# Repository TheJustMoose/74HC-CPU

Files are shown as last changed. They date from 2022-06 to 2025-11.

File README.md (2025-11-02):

# 74HCPU

Not a very scary instruction set discrete logic processor.

* 8 bit data
* 16 bit address / 64KB RAM
* 16 instructions
* 8 data registers and 4 pointer registers in 2 banks
* 1 flag register in IO port

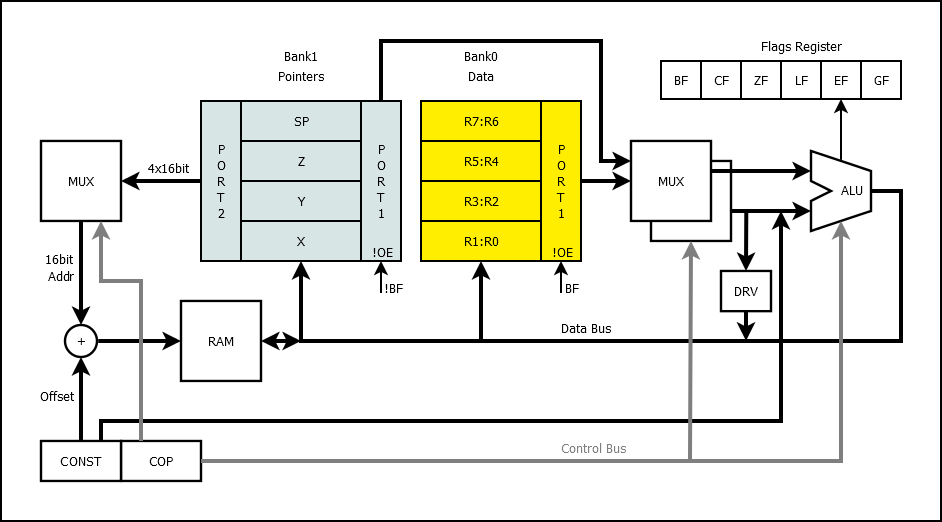
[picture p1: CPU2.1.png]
CPU structure


## How CPU works?

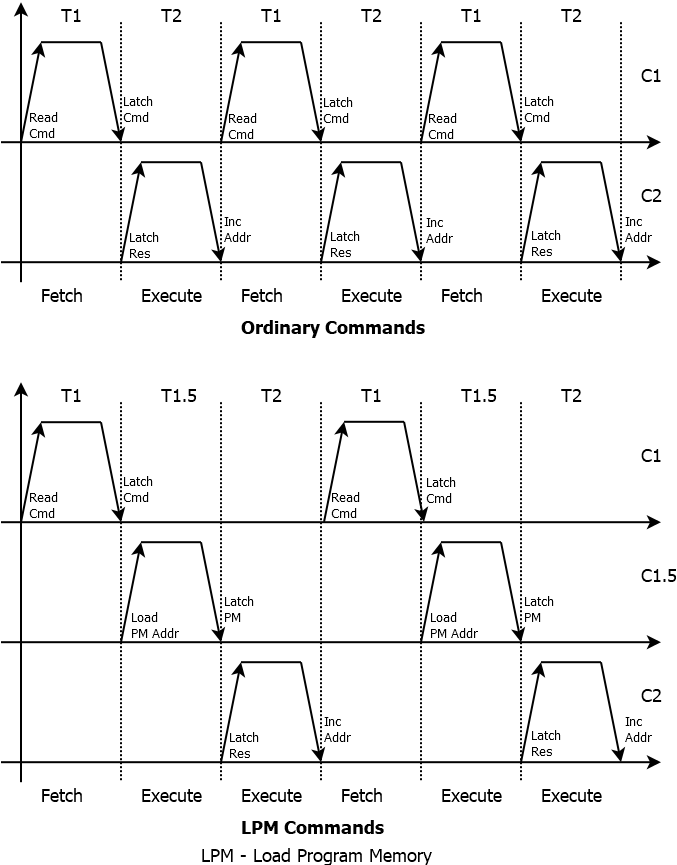
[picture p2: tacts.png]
CPU tacts


[Layers of PCBs](layers/README.md)

## Instruction list

```
|----------------------------------------------|f|
|   HIGH BYTE    |    LOW BYTE   |  HIGH BYTE  |a|
|0 1 2 3  4 5 6 7 8 9 A B C D E F|   (again)   |g|
|   4   +   3 + 1 + 3  +    5    = 16          |l|
|----------------------------------------------|s|
|   ADD |  DST |C| SRC |-|Z|z|I|i| 00 0000 0000|*|
|  ADDC |  DST |C| SRC |F|Z|z|I|i| 10 0001 0000|*|
|   AND |  DST |C| SRC |-|Z|z|I|i| 20 0010 0000|*|
|    OR |  DST |C| SRC |-|Z|z|I|i| 30 0011 0000|*|
|   XOR |  DST |C| SRC |-|Z|z|I|i| 40 0100 0000|*|
|   MUL |  DST |C| SRC |-|Z|z|I|i| 50 0101 0000|*|
|   UNO |  DST |0|-|TYP|F|-|-|-|-| 60 0110 0000|*|
|   MOV |  DST |0| SRC |*|Z|z|I|i| 70 0111 0000| |
|   LPM |  DST |W|EXT|D|U|OFFSET4| 80 1000 0000| |
|    LD |  DST |0|EXT|D|U|OFFSET4| 90 1001 0000| |
|    IN |  DST |  PORT   |Z|z|I|i| A0 1010 0000| |
|--------------|7-8-9-A-B|-------|-------------|-|
|   OUT |  SRC |  PORT   |O|o|X|x| B0 1011 0000| |
|    ST |  SRC |0|EXT|D|U|OFFSET4| C0 1100 0000| |
|   CMP |  DST |C| SRC |-|   -   | D0 1101 0000|+|
|  CMPC |  DST |C| SRC |-|   -   | E0 1110 0000|+|
| BRNCH |  CALL  | 8 bit OFFSET  | F0 1111 0000| |
| BRNCH |   JMP  | 8 bit OFFSET  | F1 1111 0001| |
| BRNCH |   RET  | 8 bit +STACK  | F2 1111 0010| |
| BRNCH |  RETI  | 8 bit OFFSET  | F3 1111 0011| |
| BRNCH |    JL  | 8 bit OFFSET  | F4 1111 0100| |
| BRNCH |    JE  | 8 bit OFFSET  | F5 1111 0101| |
| BRNCH |   JNE  | 8 bit OFFSET  | F6 1111 0110| |
| BRNCH |    JG  | 8 bit OFFSET  | F7 1111 0111| |
| BRNCH |    JZ  | 8 bit OFFSET  | F8 1111 1000| |
| BRNCH |   JNZ  | 8 bit OFFSET  | F9 1111 1001| |
| BRNCH |    JC  | 8 bit OFFSET  | FA 1111 1010| |
| BRNCH |   JNC  | 8 bit OFFSET  | FB 1111 1011| |
| BRNCH |   JHC  | 8 bit OFFSET  | FC 1111 1100| |
| BRNCH |  JNHC  | 8 bit OFFSET  | FD 1111 1101| |
| BRNCH | AFCALL | Hi 8 bit ADDR | FE 1111 1110| |
| BRNCH |NOP/STOP|   1111 111x   | FF 1111 1111| |
|----------------------------------------------|-|
```

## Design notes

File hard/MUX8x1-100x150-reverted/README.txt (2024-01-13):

This multiplexer is similar to MUX8x1-100x150, but the output connector is reversed.

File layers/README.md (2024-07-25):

# 74HCPU PCB layers

## Layer 1 (top)

<table>
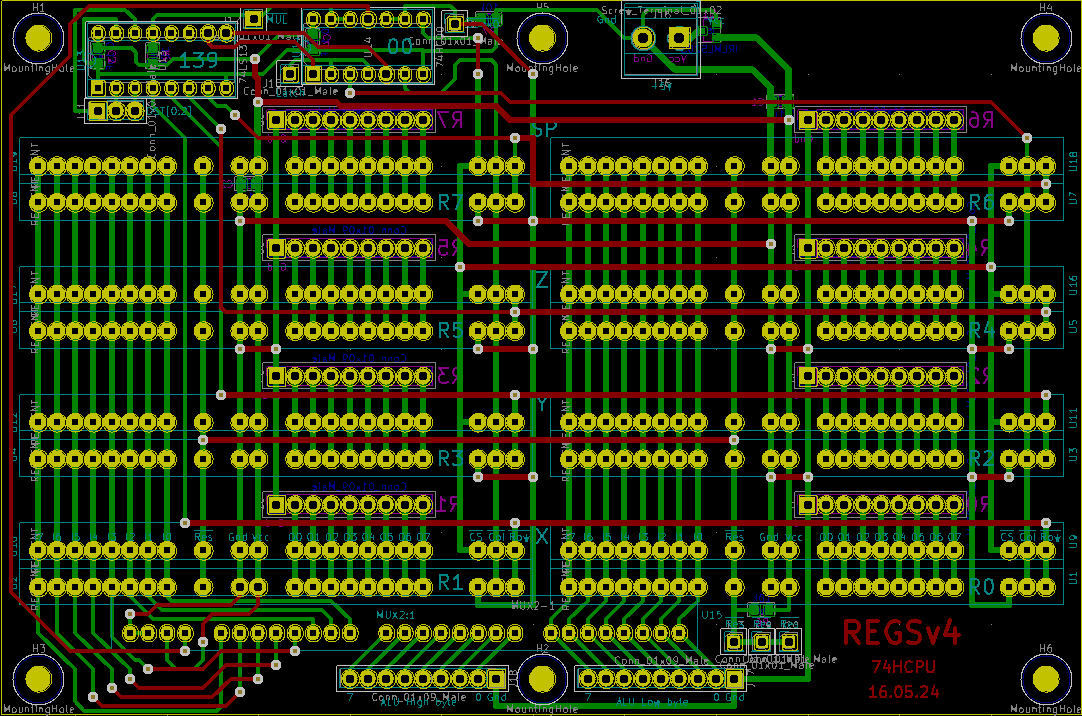
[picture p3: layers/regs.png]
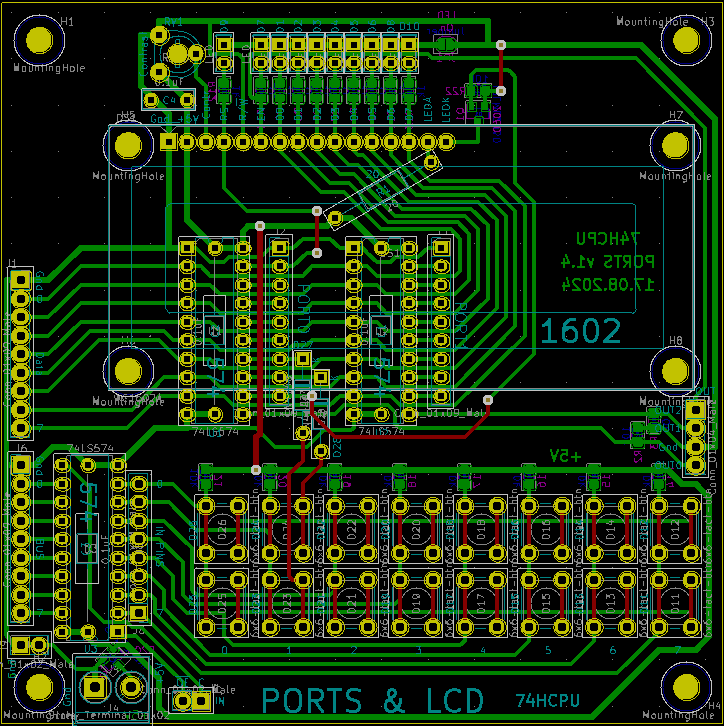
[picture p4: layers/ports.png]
<tr><td></td><td></td></tr>
</table>

## Layer 2

<table>
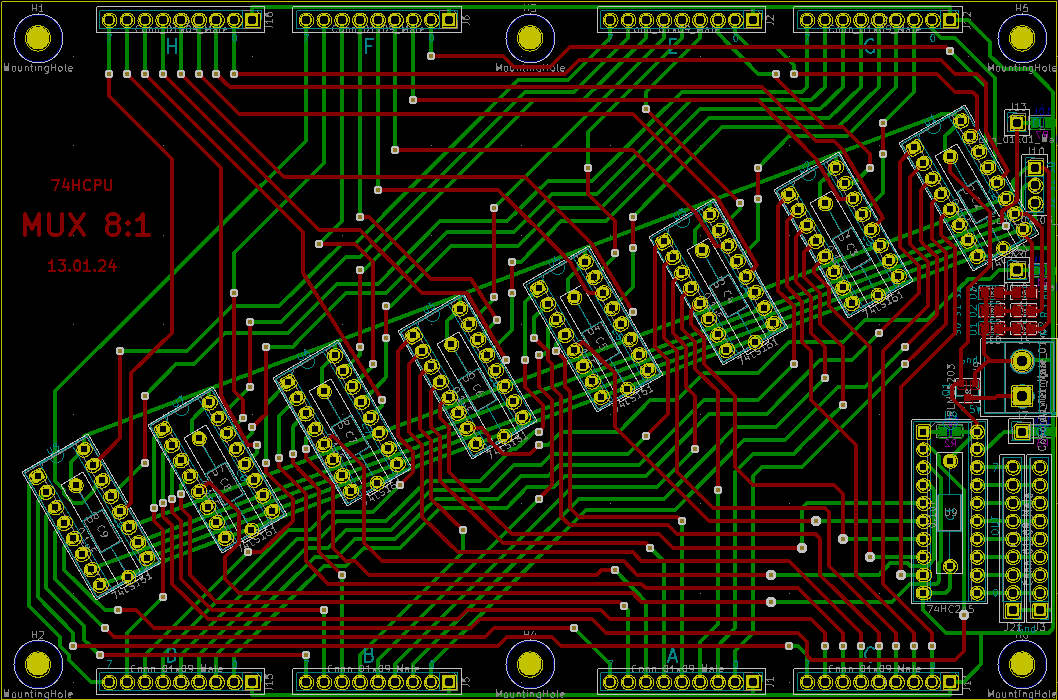
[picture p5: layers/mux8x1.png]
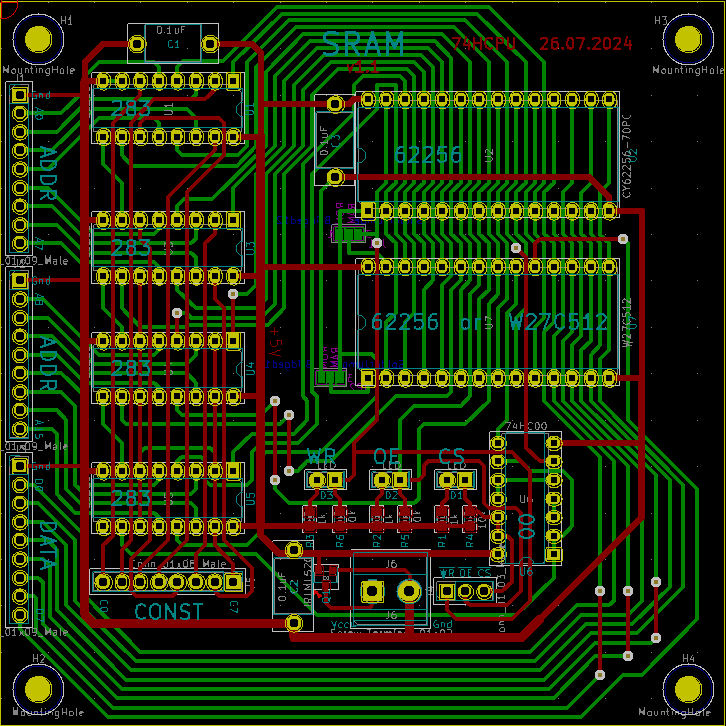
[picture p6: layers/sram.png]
<tr><td></td><td></td></tr>
</table>

## Layer 3

<table>
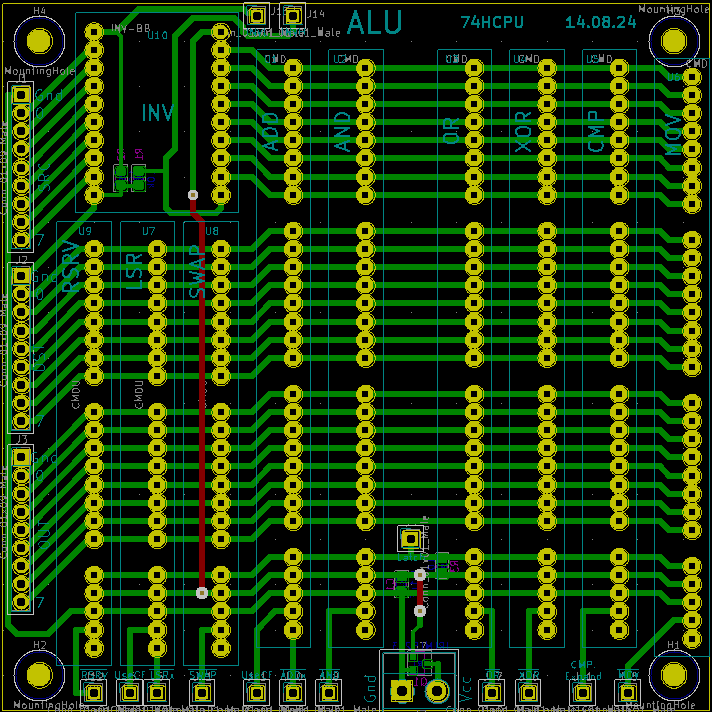
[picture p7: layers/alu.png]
<tr><td></td><td></td></tr>
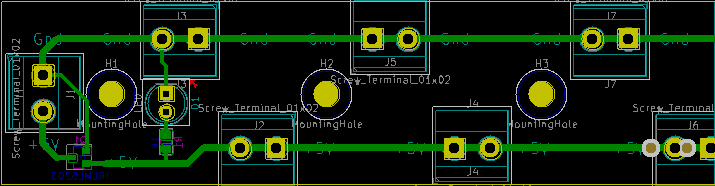
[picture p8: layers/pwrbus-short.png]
<tr><td></td><td></td></tr>
</table>
<table>
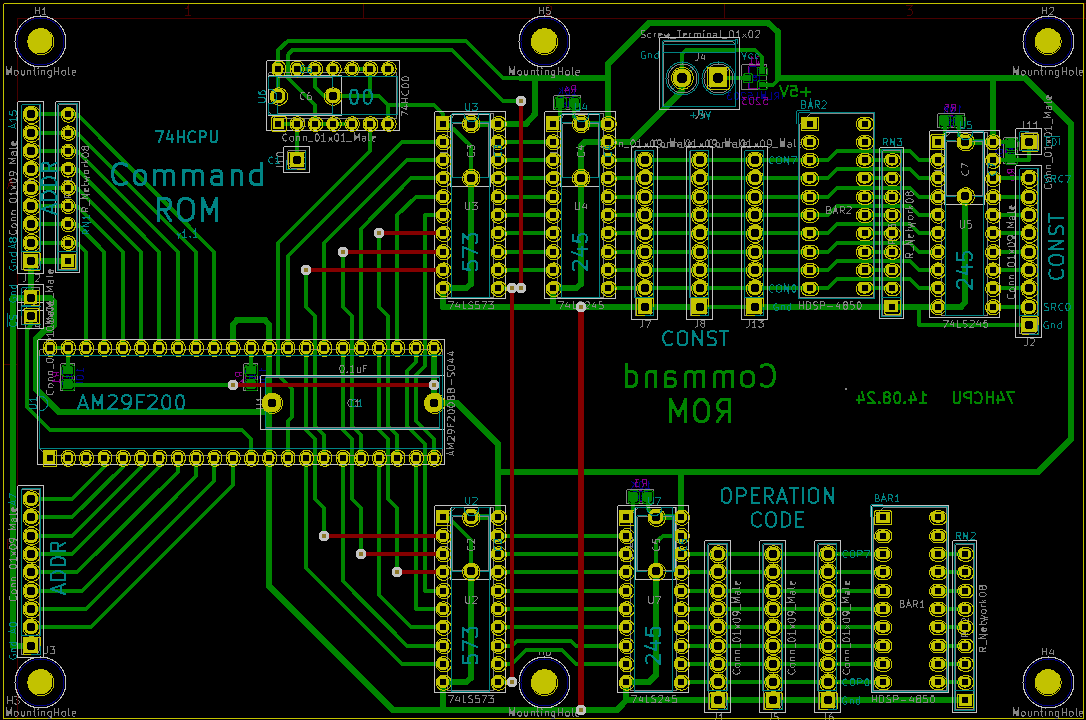
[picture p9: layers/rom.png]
<tr><td></td><td></td></tr>
</table>

## Layer 4 (bottom)

<table>
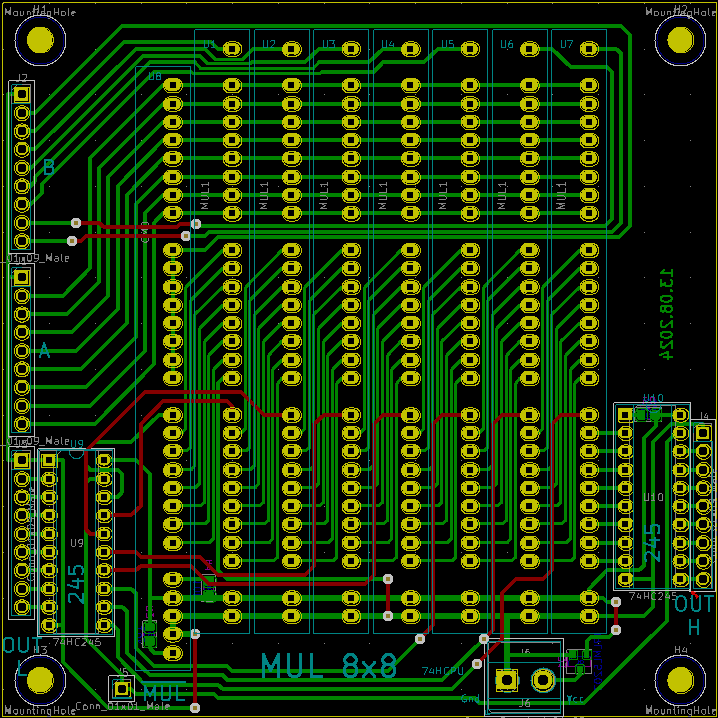
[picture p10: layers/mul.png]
<tr><td></td><td></td></tr>
<tr><td></td><td></td></tr>
</table>
<table>
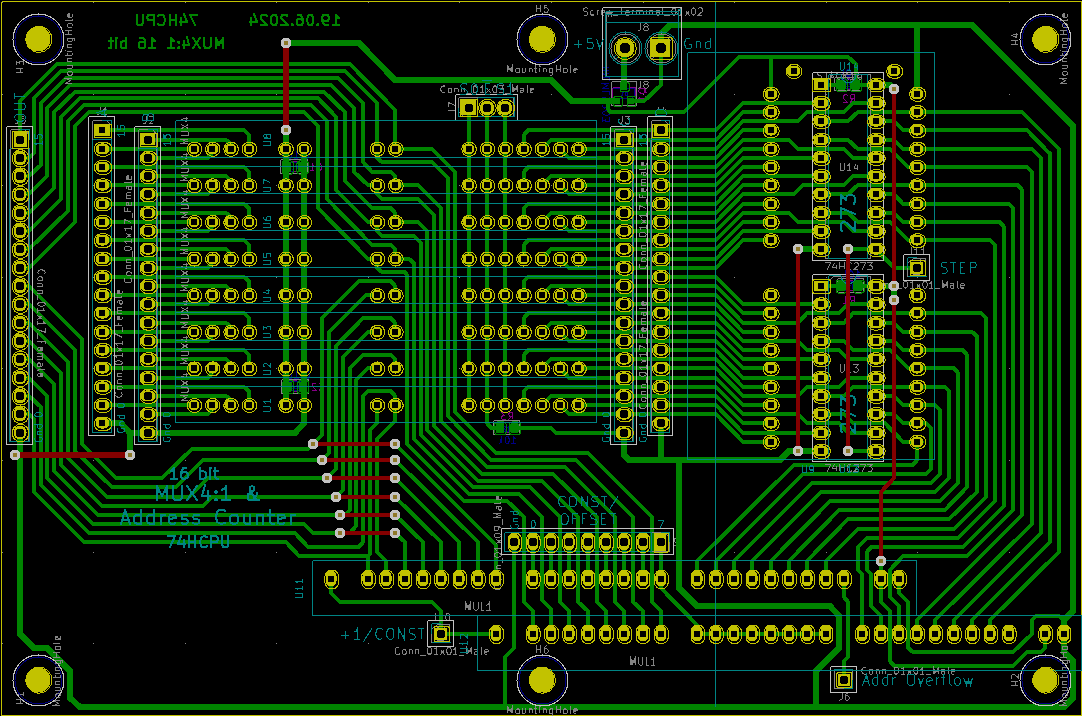
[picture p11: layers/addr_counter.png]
<tr><td></td><td></td></tr>
</table>

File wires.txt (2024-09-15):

Список пинов/проводов/контактов на разных платах и их значение:

ROM
A0-A15 - вход, шина адреса, какие данные читать из ROM
CS - вход, включить микросхему ROM
C1 - вход, сигнал, по которому данные читаются из ROM и записываются в регистры
COP0-COP7 - шина, содержит команду, которую нужно выполнить
 (при выполнении команды LPM содержит старший байт данных)
CNST0-CNST7 - шина, содержит константу или адрес, которые используются в команде
BUS0-BUS7 - шина, содержит константу, которую можно подать шину данных,
 активируется сигналом LDI
LDI - вход, сигнал, переводит шинный формирователь в активное состояние и на шине данных появляется константа

RAM
A0-A15 - шина адреса
D0-D7 - шина данных, активируется сигналом логического 0 на входе OE
C0-C7 (CONST) - смещение, складывается со значением на шине адреса,
 сумма подаётся на шину адреса ОЗУ
CS - логический 0 активирует ОЗУ
OE - логический 0 подключает выходы озу к шине данных
WR - логический 0 производит запись данных с шины данных
 в ячейку памяти, адрес которой равен сумме шины адреса и константы

Regs
ALU Low Byte - вход данных, подключен к АЛУ, младший байт
ALU High Byte - вход данных, подключен к АЛУ, старший байт, нужен для команды MUL
 (эти же входы могут получать данные с RAM, ROM (LPM), портов)
Bank0 - вход, активирует регистры из банка 0
 (если подать логическую единицу включится банк 1)
Latch - вход, по этому сигналу данные запишутся в регистр
DST[0:2] - вход, в какой регистр писать данные по сигналу Latch
MUL - вход, активируется логическим 0, если активен - данные с ALU Low/High Byte
 будут записаны в два соседних регистра
Res - вход, если подать логическую 0, то все регистры обнулятся
R0-R7 - выходы регистров, подключаются к мультиплексорам

ALU
SRC - вход данных 1, подключен через мультиплексоры к регистрам данных
DST - вход данных 2, подключен через мультиплексоры к регистрам данных
OUT - выход данных, результаты вычисления
INVL, INVH - вход, инвертировать данные, полученные со входа SRC
 (можно отдельно младшую и старшую половны)
Latch - вход, по этому сигналу защёлкиваются данные внутри команд
 (сейчас не используется, данные сразу оказываются на выходе)
входы активации команды, записанные ниже, можно активировать только по одной штуке
 (иначе случиться короткое замыкание и всё сгорит):
ADDx - вход, активировать команду сложения
UseCF - нужно ли дополнительно прибавлять бит CF к сумме (ADDC)
AND/OR/XOR - логические команды
MOV - просто передаёт данные со входа SRC на выход OUT
команда CMP всегда сравнивает SRC и DST и всегда выдаёт результат на своих выходах
 (у этой команды OUT является входом, на нём проверяется наличие нуля)
CMP.Expand превращает команду CMP в CMPC, то есть, в сравнении участвует флаг CF

унарные команды, получают данные на входе DST, выдают результат на выходе OUT:
SWAP - активирует команду SWAP, переставить местами нибблы
LSRx - побитовый сдвиг вправо
UseCF - в процессе сдвига участвует флаг CF
RSRV - активирует команду RSRV, собственно, туда можно воткнуть что угодно ;)

MUL
A - вход данных 1, подключен через мультиплексоры к регистрам данных
B - вход данных 2, подключен через мультиплексоры к регистрам данных
OUTL - выход данных, результат вычисления, младший байт
OUTH - выход данных, результат вычисления, старший байт
MUL - вход, при подаче логического 0 выходы данных переходят из Z состояния в рабочее

MUX8:1
A-H - 8 входов данных, подключаются к регистрам
OUT - выход данных, подключается к ALU, MUL, ...
OE - вход, при подаче логического 0 выход данных переходит из Z состояния в рабочее
S0-S7 - входы, выбирают какой из входов данных будет подключен к выходу
EL, EH - входы, позволяют занулить один или оба ниббла выходных данных

Ports
Data - вход данных, подключен к LCD и паре регистров
BUS - выход данных, активируется логическим 0 на входе IN0.OE
IN0.C - вход, защёлкивает данные в выходном регистре по фронту импульса
IN0.OE - вход, подключает выходной регистр к шине BUS по логическому 0 на этом входе
OUT0 - защёлкивает данные в PORT0 по фронту импульса
OUT1 - защёлкивает данные в PORT1 по фронту импульса
OUT2 - подключен ко входу E LCD 1602, подробности в описании LCD 1602
регистр PORT0 имеет выходы, подключенные к входу RS LCD, кнопкам, подсветке LCD

Addr Counter
A, B, C, D - 16 бит входы мультиплексора,
 вход C подключен к выходу стека, вход D подключен к регистру адреса
O(OUT) - выход мультиплексора
+1/CONST - вход, при логической 1 делает шаг вперёд на CONST,
 при логической 0 делает шаг вперёд на 1
STEP - вход, шаг происходит по фронту импульса
S0-S1 - входы, выбирают один из входов A, B, C, D и подключают его к O
E - вход, при подаче логического 0 зануляет выходы O
входы стека подключаются навесным монтажём к логике

Flags гипотетический
GT, LT, EQ, ZF, CF1, CF2 - входы флагов
C2 - тактовый вход
CF Enable - вход, разрешает запись флага CF
ZF Enable - вход, разрешает запись флага ZF
CMP Enable - вход, разрешает запись флагов GT, LT, EQ
Res - вход, если подать логическую 0, то все флаги обнулятся
 (кроме EQ, он инверсный)
GT, LT, EQ, ZF, CF(три раза) - вЫходы флагов
(плюс инверсные CF и ZF)
НЕ ХВАТАЕТ!
HCF, BG, DBG

CMD_DEC гипотетический
входы:
COP0-COP3
C1
C2
SRC0-SRC2
выходы:
ADD, ADDC, ....
RAM_OE
RAM_WR
RAM_CS
CMP_EN
CF_EN
ZF_EN
LSR, SWAP, RSRV
UseCF
WILL_WR2REG
LATCH_REG
НЕ ХВАТАЕТ!
INVL, INVH
?

JUMPS гипотетический

Toggle

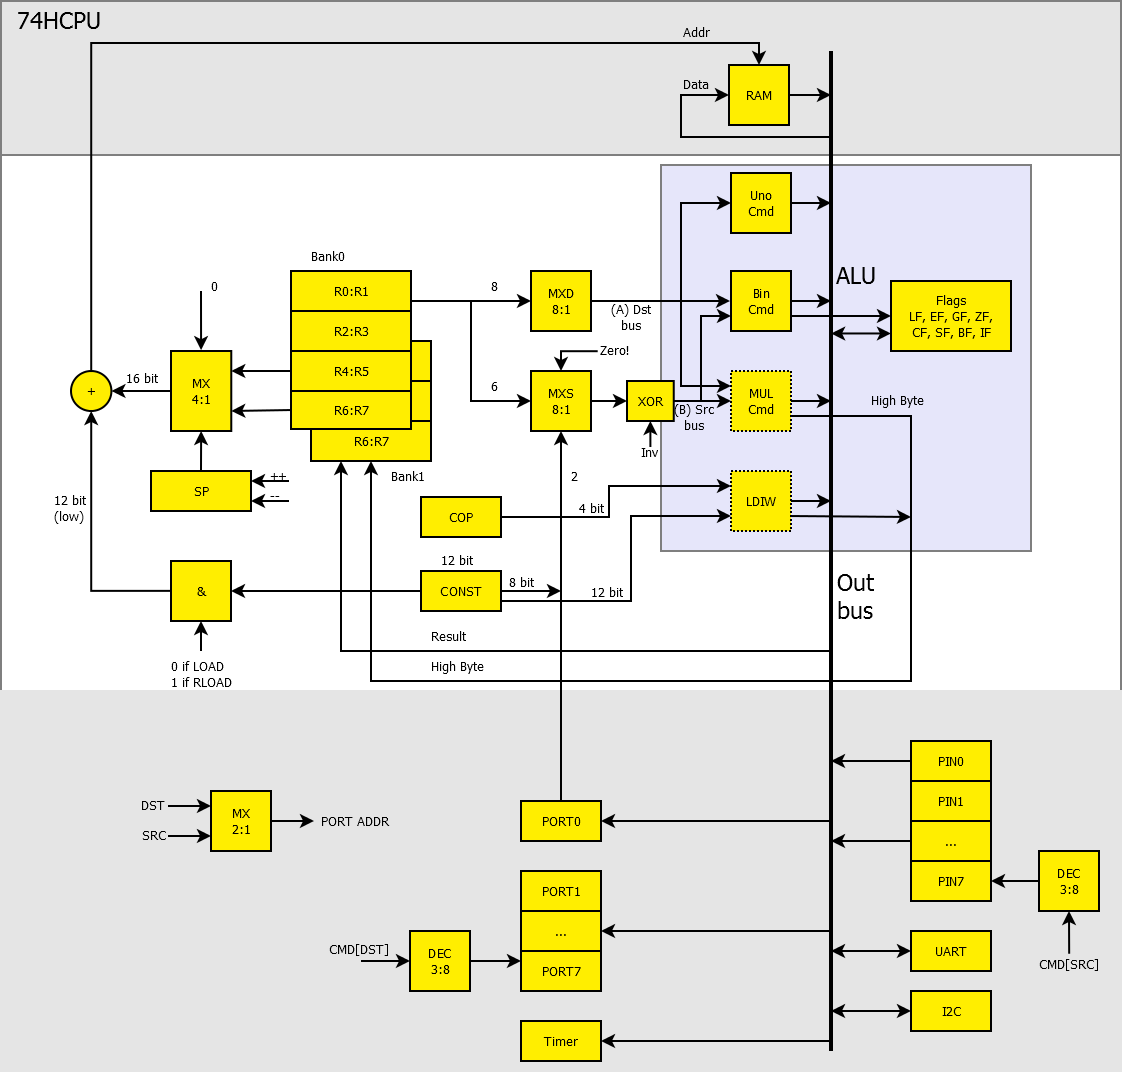
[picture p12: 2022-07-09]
CPU.png

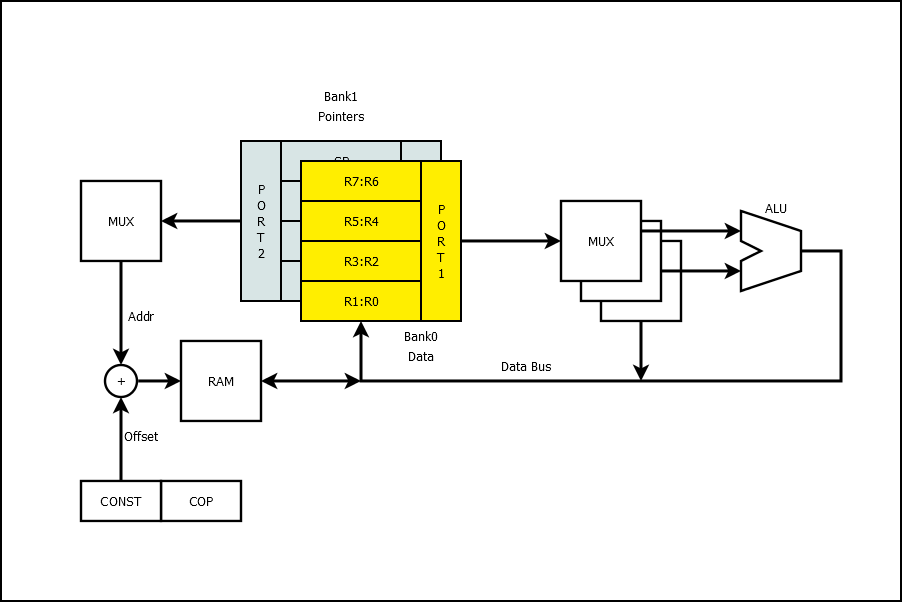
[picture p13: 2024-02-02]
CPU2.png

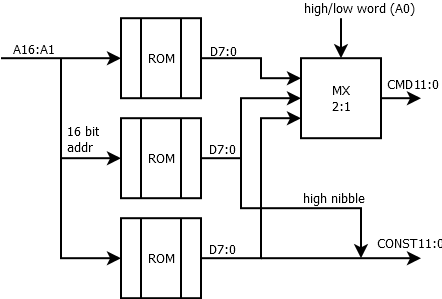
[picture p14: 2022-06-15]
Trash/ROM.png

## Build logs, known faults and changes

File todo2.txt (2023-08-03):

сделать стек для вызовов функций
(платы есть, нужно только спаять, и воткнуть в монтажку)
реализовать команду INC
спаять 3x MUX8:1
спаять 8x Reg
выкинуть из АЛУ команду INV
вынуть из АЛУ RAM
поместить плату RAM под АЛУ
поменять местами СЗР и МЗР у мультиплексоров, чтобы кабели не перекручивались
добавить защиту от переполюсовки, везде!!
переделать CMD_DEC, поменять местами BRNCH и CMP, добавить генерацию сигнала переключения на константу
добавить светодиодов на генератор тактовых сигналов
+придумать/переделать сигнал LATCH для OUT/LCD
новая плата портов
написать простейшие функции вывода на LCD
написать простейший калькулятор :)
+нарисовать схему тактового генератора
добавить в неё третий такт для LPM
нарисовать плату тактового генератора
новая плата RAM
собрать плату регистров, например из stripboard-а
перекоммутировать проводочки src/dst
протестировать (написать тесты на все команды)
сделать плату UART
дождаться новых регистров
+дождаться счётчиков из Чип-Дипа
спаять новые регистры
реализовать автоинкремент указателей!
переделать счётчик адреса на MUL1
сделать его 16 битным
дождаться мультиплексора 16 бит
добавить к счётчику адреса мультиплексор 16 бит
реализовать команду LPM, без неё совсем грустно
написать ассемблер, опять
проверить максимальную тактовую частоту!!
добавить к регистру флагов
 ещё один бит для переноса из 4 бита,
 ещё пинов, и, кажется, элемент ИЛИ для ForceCF == INC
добавить к условным переходам новый флаг
попробовать сделать команду compare, skip if not equal (или какое-то другое условие)
сделать плату для XOUT (две?)
реализовать команду XOUT
добавить для команды IN возможность инверсии
написать эмулятор 8051 ;)
поменять 1602 на какой-нибудь gLCD
реализовать механизм прерываний
найти старый RTC с параллельной шиной и вкрутить его
придумать что-то с таймерами
досыпать светодиодов на плату RAM
написать библиотеку функций
написать свой BASIC *ROFL*
опять таки, интерпретатор можно положить в ROM, а программу в RAM
добавить мультиплексор для команд ADDI/ANDI/...
написать какую-нибудь игру!
придумать, как прикрутить клавиатуру крупнее чем 16 клавиш ;)
придумать какую-то шину ввода-вывода для расширения железа!
 (а-ля ISA)

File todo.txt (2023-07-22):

ZF должен защёлкиваться по арифметическим командам, а не по CMPx
потерялись светодиоды индикации банков

проверить размер микросхем на плате регистра
проверить размер фрезы во фьюжене на плате регистра, поменять на 0.9
протравить пару регистров
набить пару регистров
набить и протестировать плату регистров
купить текстолита и лужёного провода
собрать новый фрезерный станок
купить новый монитор помельче
попробовать фрезернуть мелкую плату прям по контуру дорожек
 (только нету фрезы 0.5)
кажется, у АЛУ нет подключения шинного формирователя к BUS для команды OUT
добавить на плату АЛУ типа монтажку, ибо наверняка какой-нибудь микросхемы не хватит
добавить подписей пинов на плату АЛУ
собрать уже наконец пульт управления для проца

нарисовать свежих монтажек, с Т образным расположением площадок
(два размера, для мелких плат с флагами и для ROM)
написать ассемблер
написать отладчик
начать рисовать в KiCAD схемы модулей

+Proto50x70-4er
+Proto100x150
+Proto100x150-4er

07.11.2022:
+набить платы AND/OR/XOR
+набить платы MUX4:1
+пересобрать проц и протестировать
 (в результате должно стать больше места и меньше багов)
+нарисовать/заказать платы AND&ADD
 (а также новые MUX4:1 и RegLED, регистр флагов?)
+протравить/набить платы RegLED
переделать монтажку регистров на 4 платы
набить плату RegLED
+сделать плату LCD, поставить на освободившееся место!
+протравить/набить плату CMP
что-то сделать с оставшимися платами INV, MOV
+начать собирать регистр флагов на освободившемся месте
+переделать команды условных переходов О_О
добавить команды SWAP, SHL, SHR
+что-то придумать с хранением бита переноса
сделать стек поглубже
придумать уже подходящий код для тестирования!
+получить платы AND&ADD и сделать уже умножение! :))
поменять LCD 1602 на gLCD
протестировать максимальную частоту *ROFL*

перенести на плату ROM?
+перейти на 12бит коды операций? уже, фактически, 16 битные
+сделать MUX8:1?
добавить команд вычитания и т.п.?

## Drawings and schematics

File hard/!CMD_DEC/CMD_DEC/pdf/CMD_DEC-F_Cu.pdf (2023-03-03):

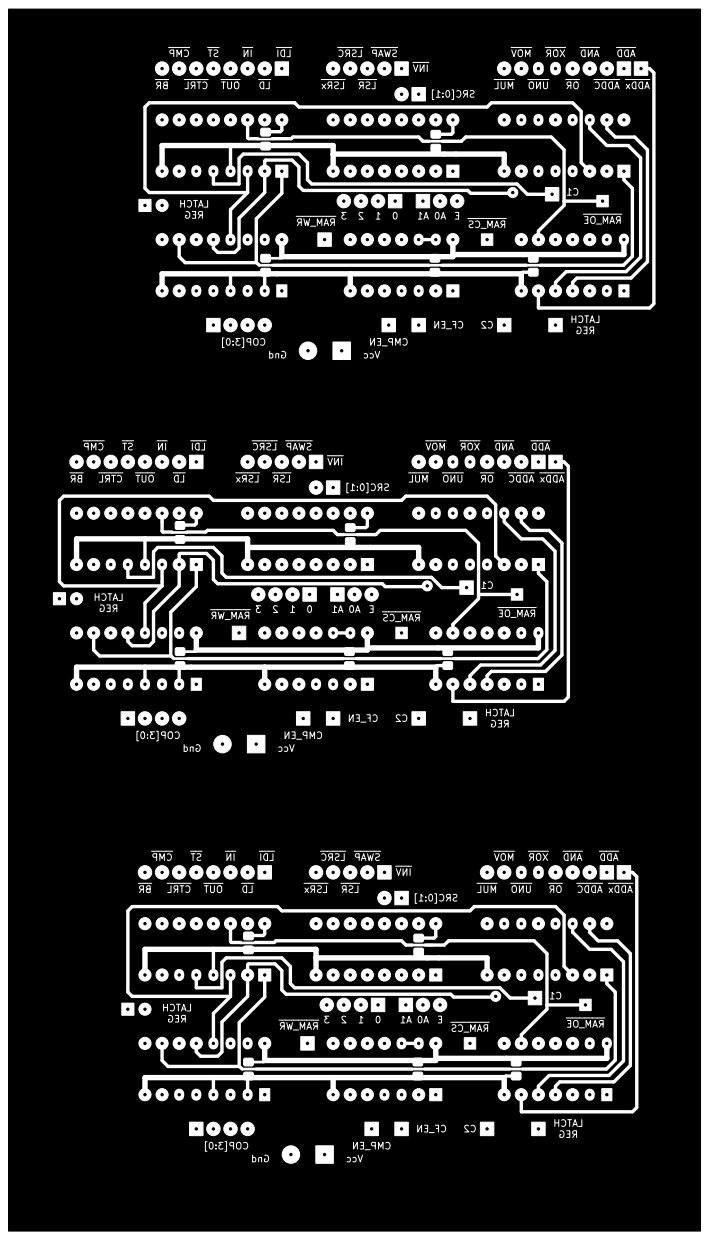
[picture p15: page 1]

CMP ST IN LDI

LSRx SRC[0:1] MUL UNO OR ADDC ADDx MOV XOR AND ADD

RAM_WR RAM_CS BR CTRL OUT LD

ADDC ADDx AND Gnd

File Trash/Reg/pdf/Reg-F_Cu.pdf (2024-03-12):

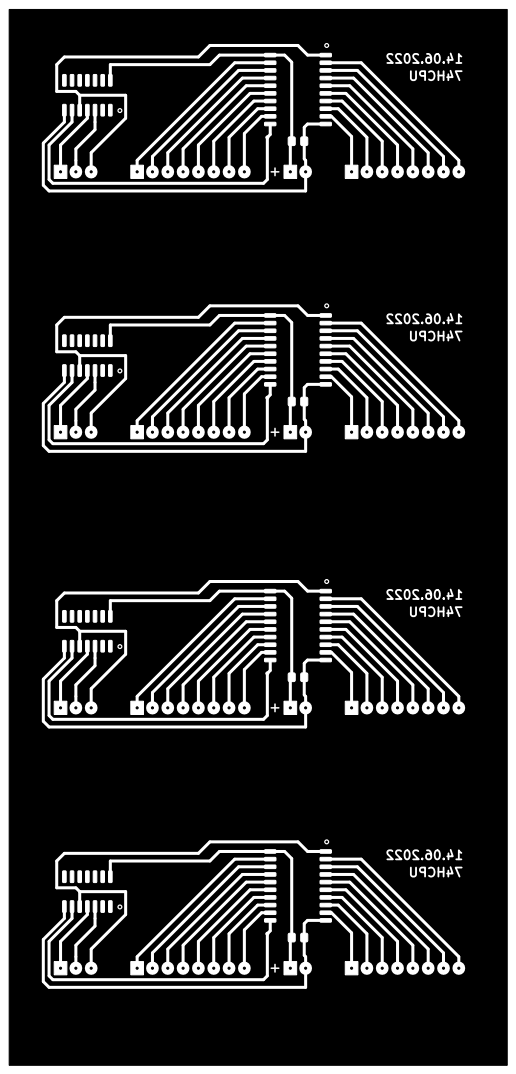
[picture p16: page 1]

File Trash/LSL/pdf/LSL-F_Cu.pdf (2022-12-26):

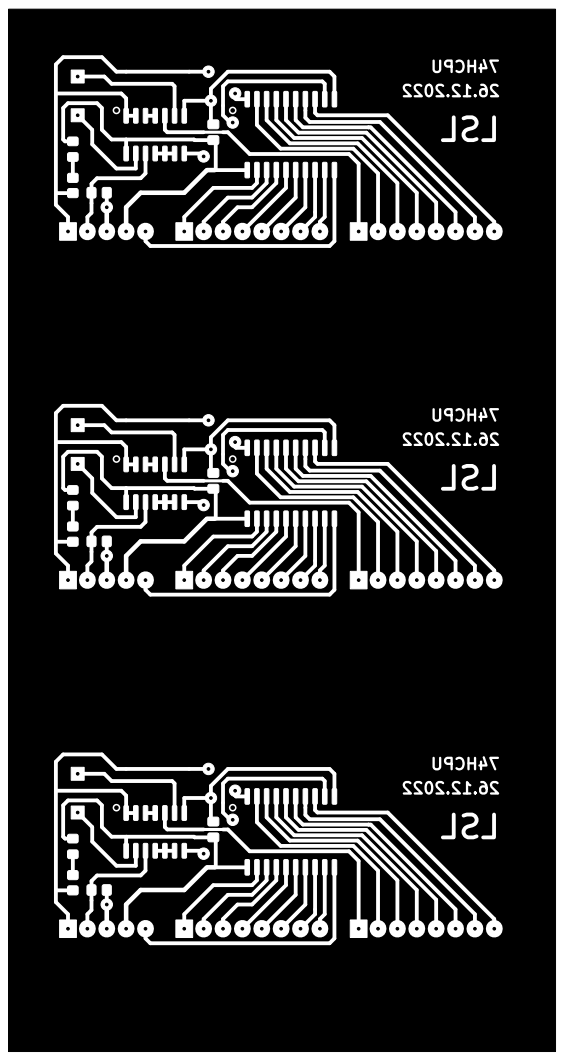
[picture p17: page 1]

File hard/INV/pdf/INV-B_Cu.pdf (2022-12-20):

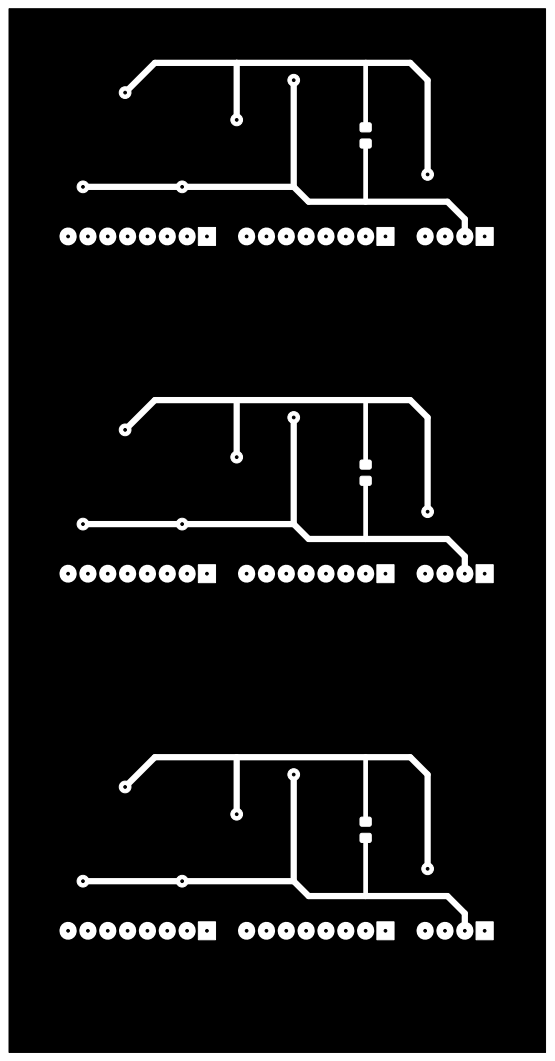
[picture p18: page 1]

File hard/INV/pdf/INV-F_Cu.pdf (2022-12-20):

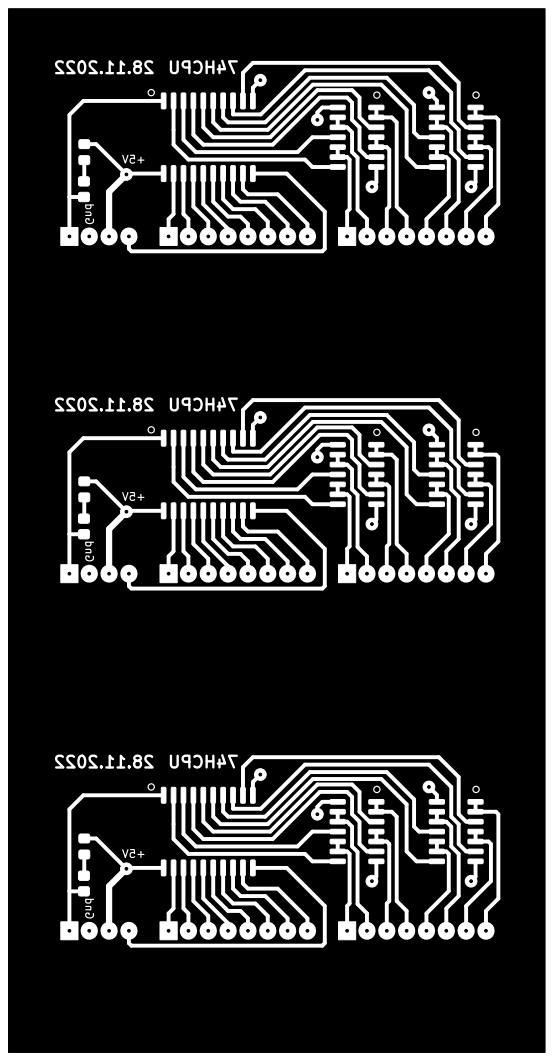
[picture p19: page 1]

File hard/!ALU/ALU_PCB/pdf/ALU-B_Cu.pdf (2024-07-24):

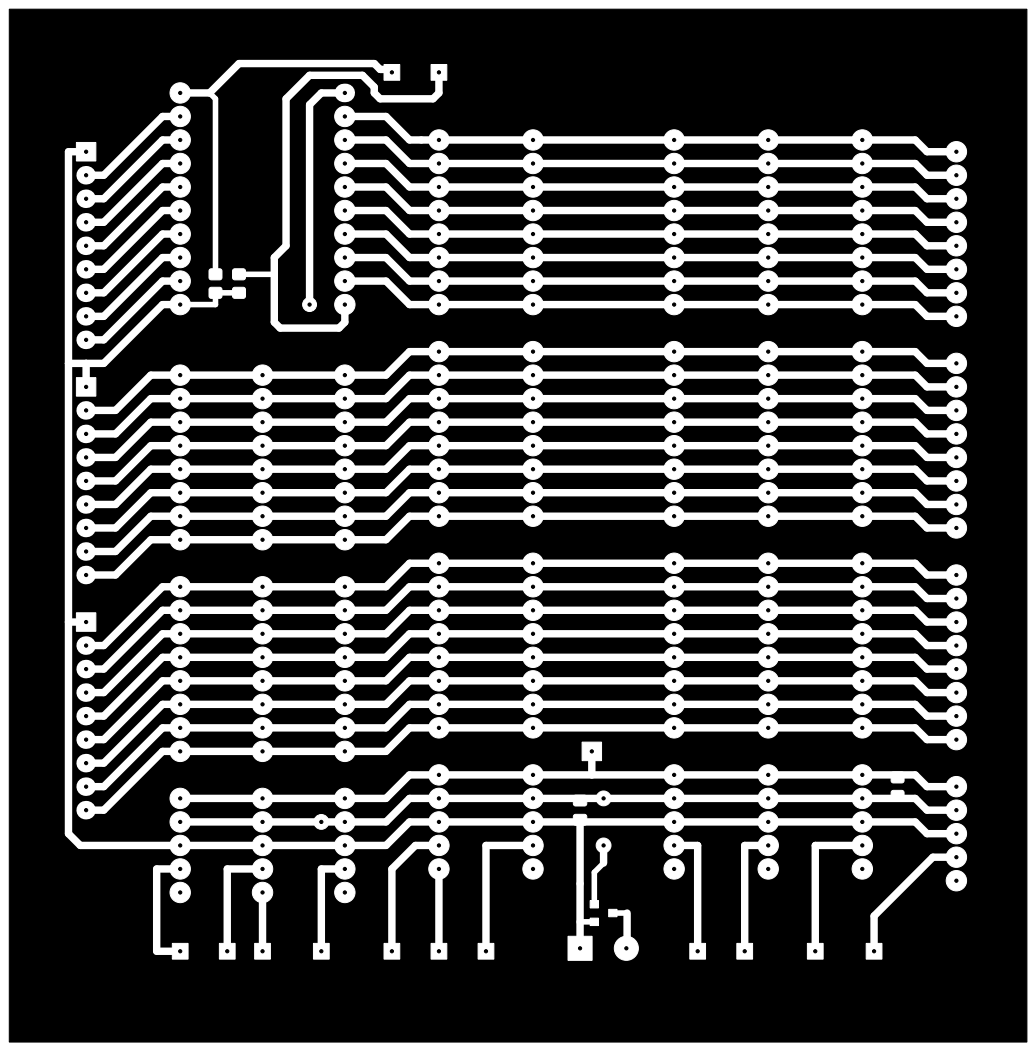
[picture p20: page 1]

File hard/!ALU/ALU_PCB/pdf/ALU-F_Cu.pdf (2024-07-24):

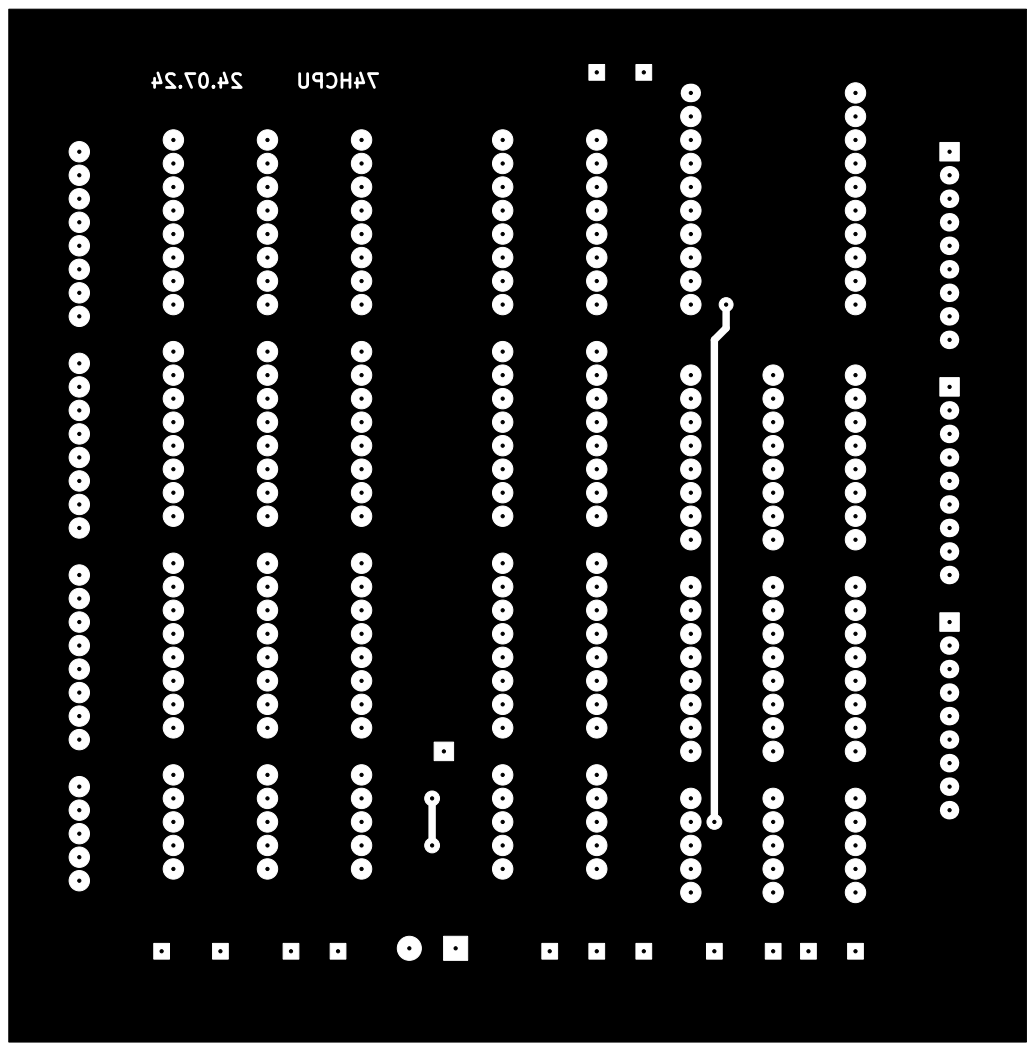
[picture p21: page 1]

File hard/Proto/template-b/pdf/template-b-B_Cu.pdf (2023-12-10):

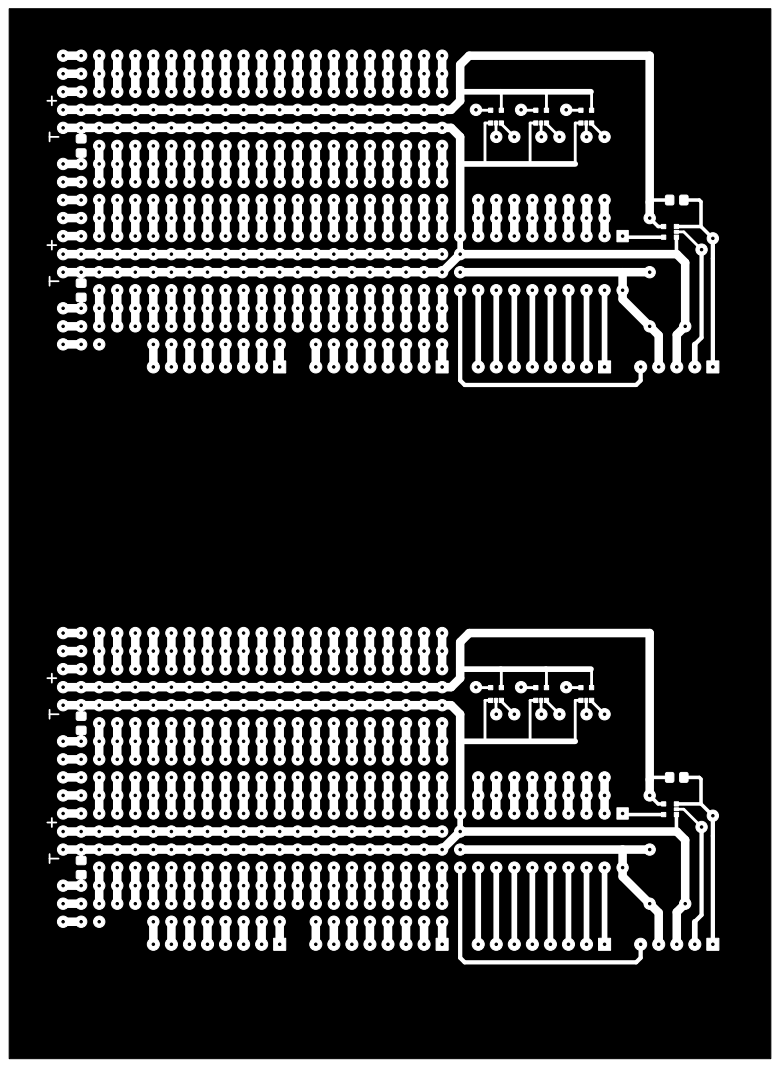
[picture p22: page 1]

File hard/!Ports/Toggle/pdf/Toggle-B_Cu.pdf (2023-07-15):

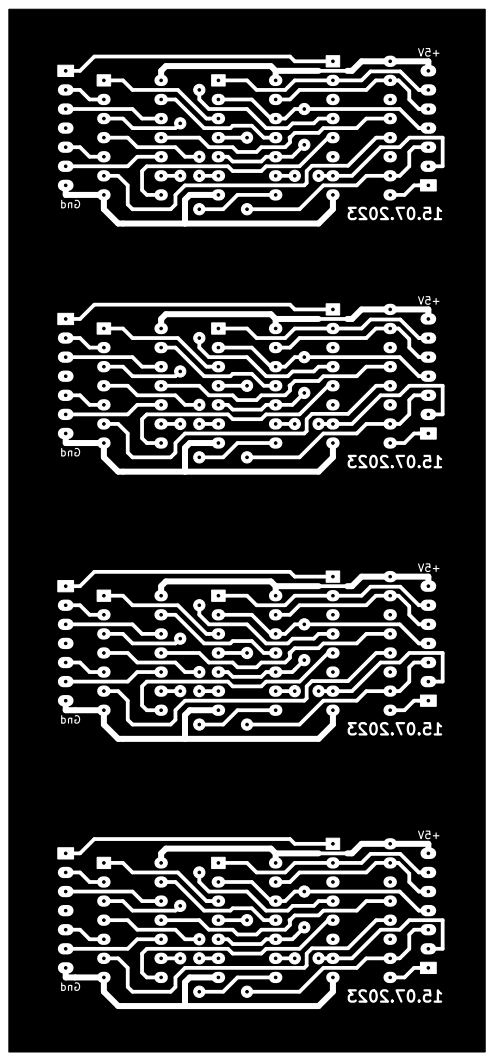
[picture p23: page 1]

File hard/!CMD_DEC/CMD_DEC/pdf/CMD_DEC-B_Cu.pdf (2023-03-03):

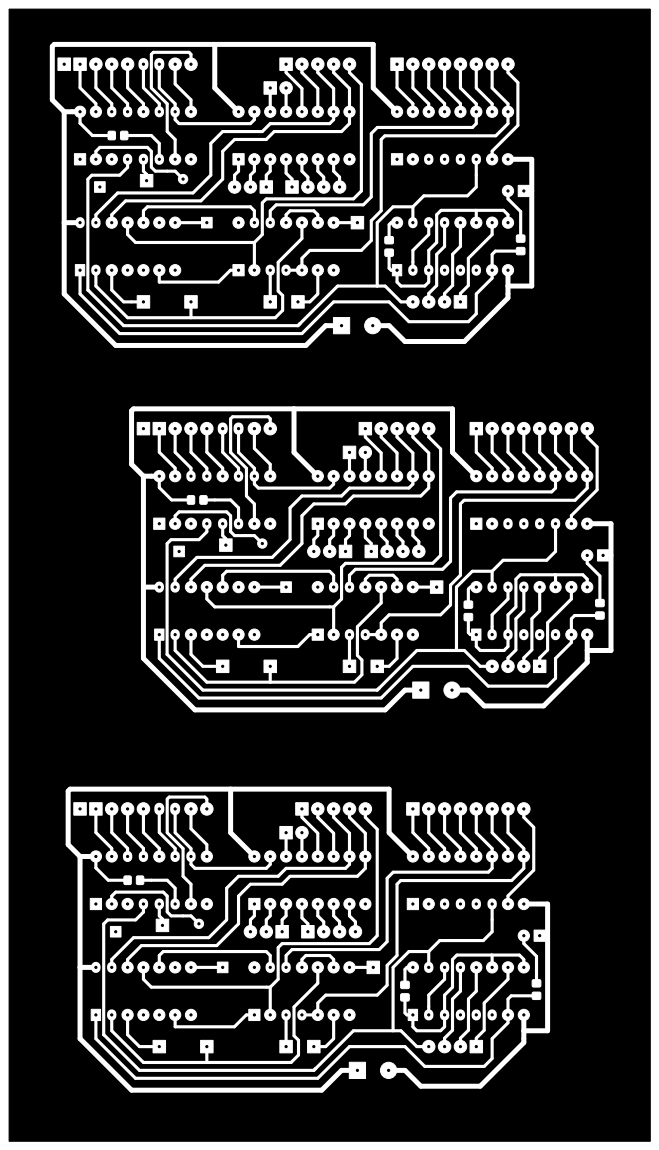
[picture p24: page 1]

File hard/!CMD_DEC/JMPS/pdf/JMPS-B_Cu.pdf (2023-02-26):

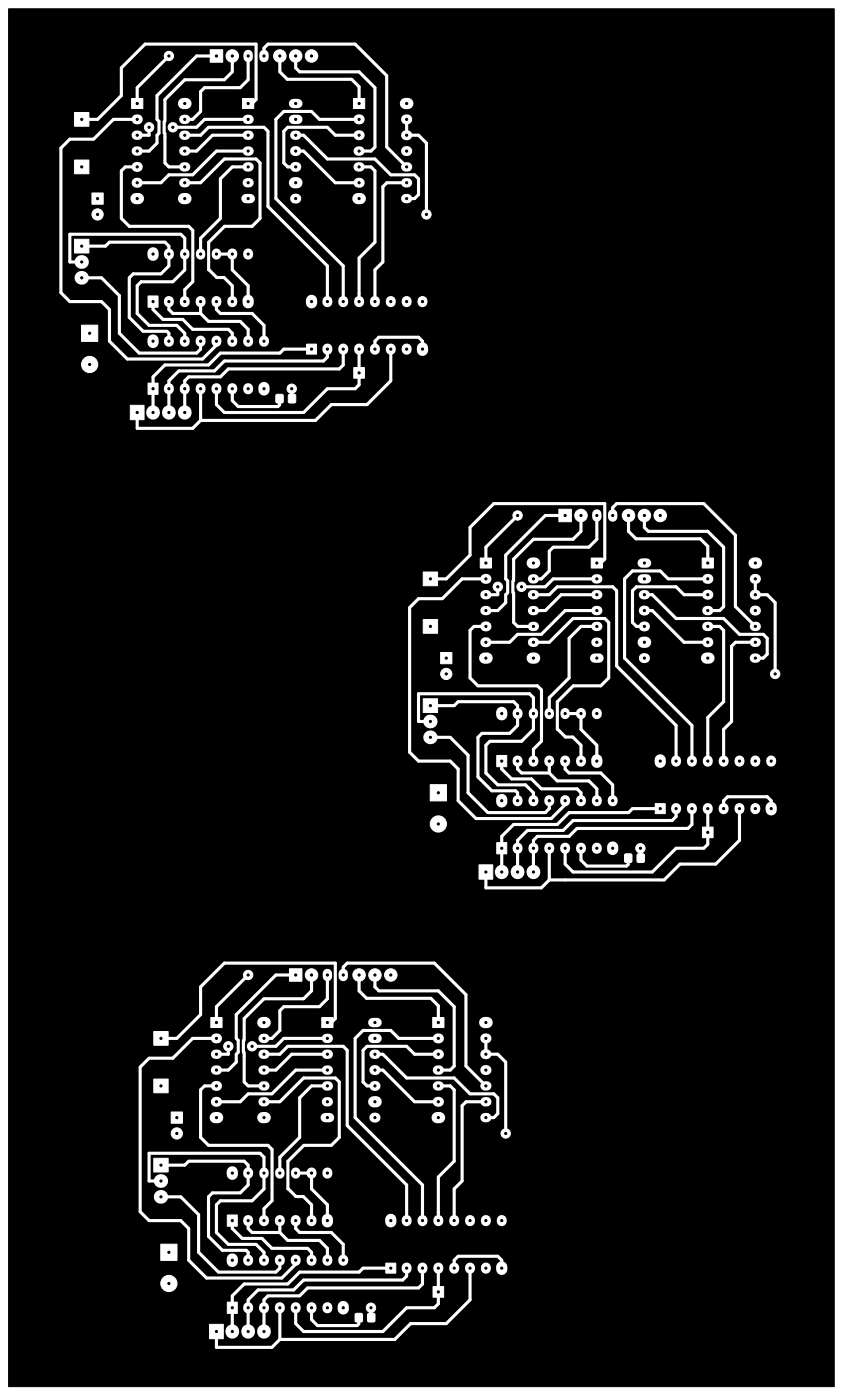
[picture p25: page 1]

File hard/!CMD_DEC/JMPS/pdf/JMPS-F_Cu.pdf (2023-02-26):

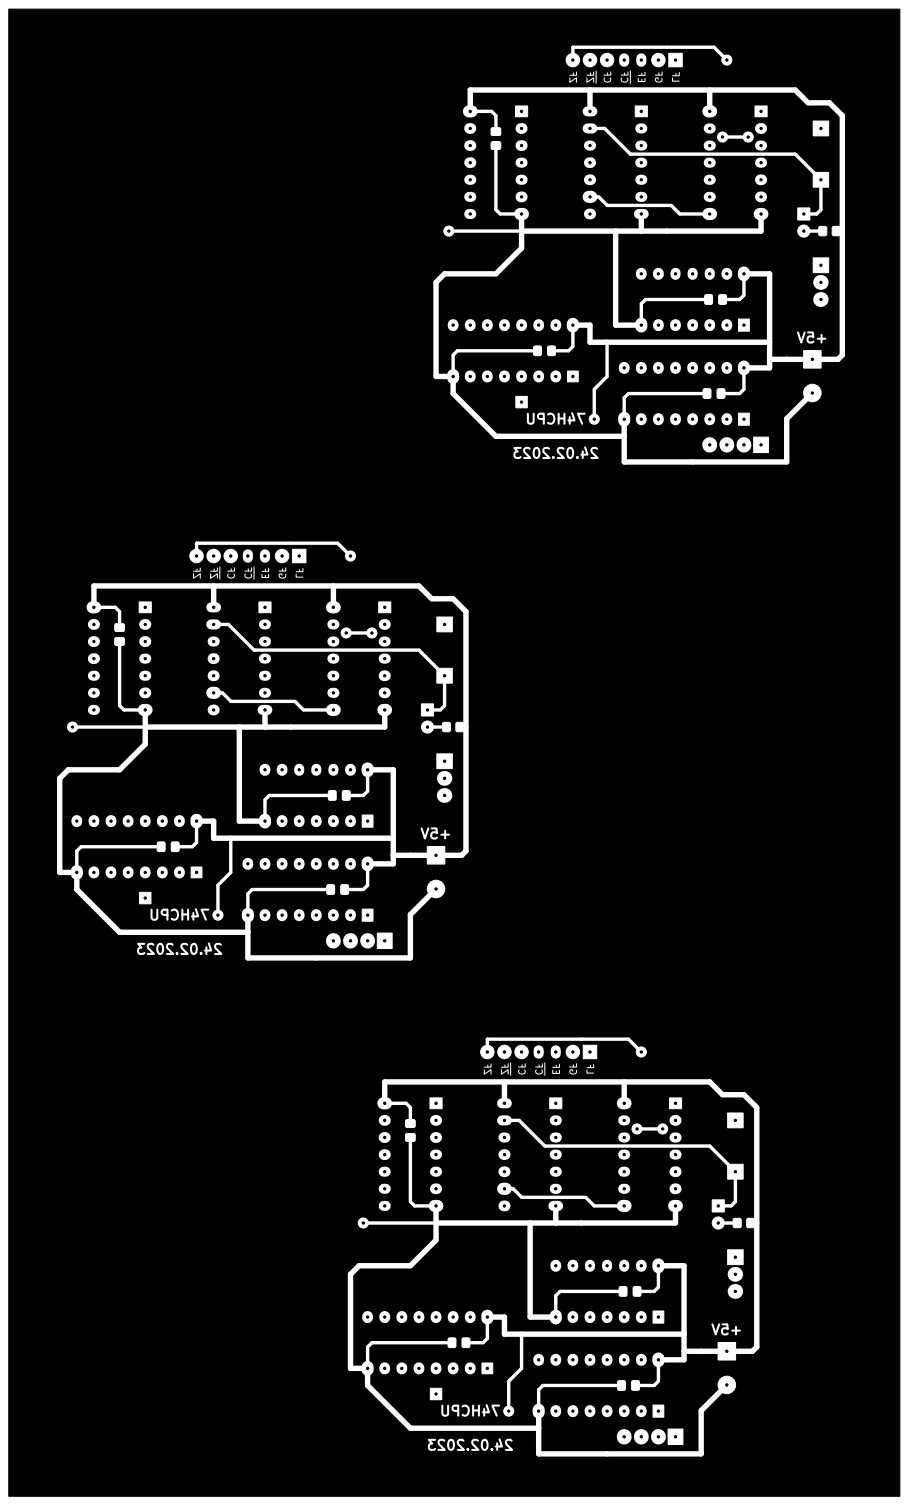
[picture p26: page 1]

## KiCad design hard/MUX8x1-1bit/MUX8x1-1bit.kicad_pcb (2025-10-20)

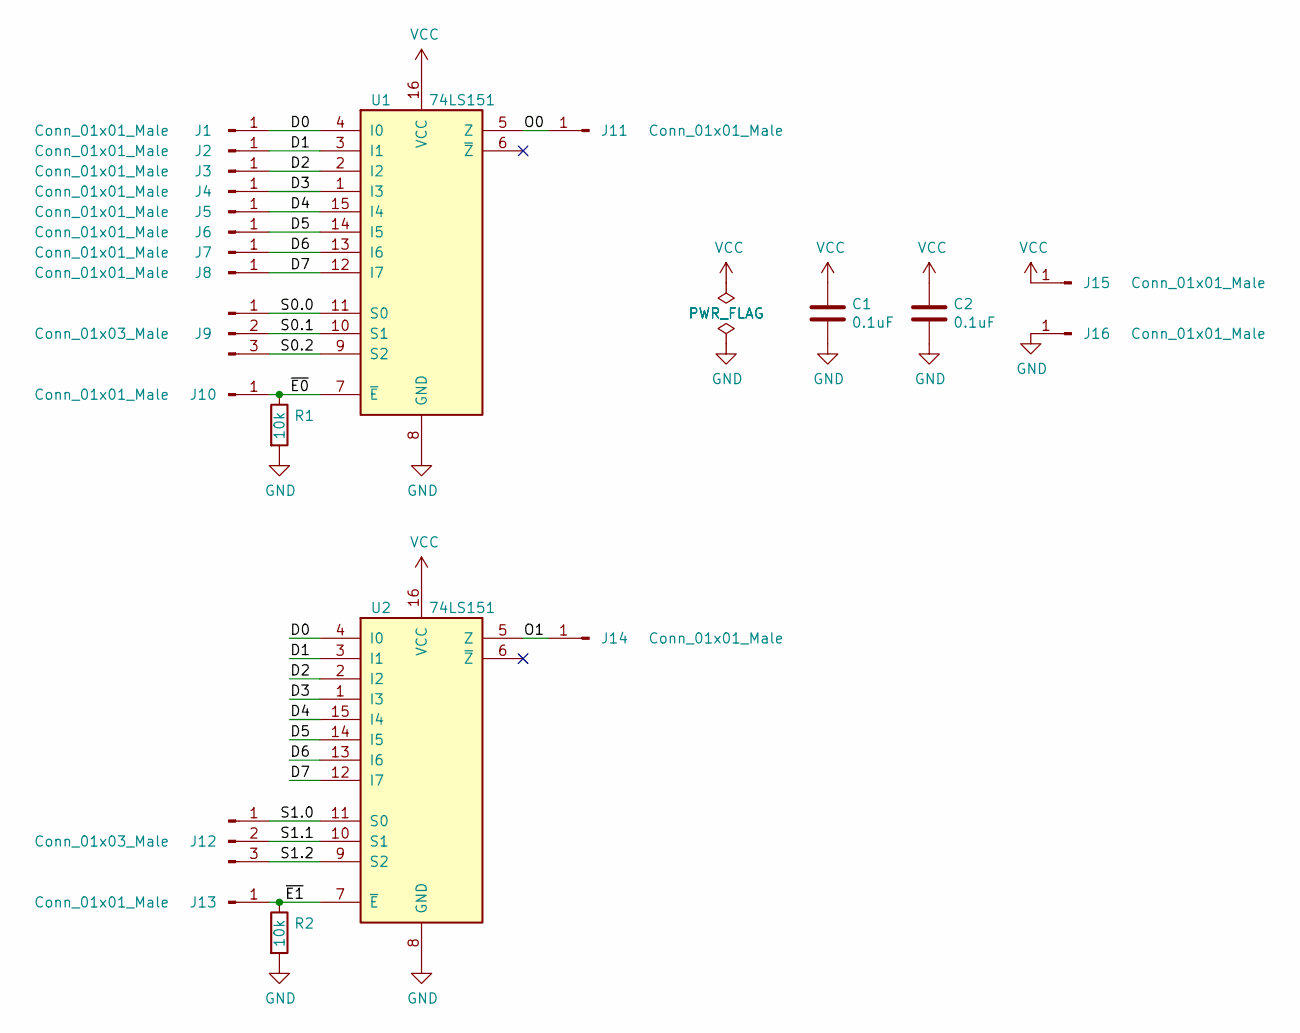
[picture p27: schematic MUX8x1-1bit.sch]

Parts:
C1, C2: 0.1uF; C_0805_2012Metric_Pad1.18x1.45mm_HandSolder
J1, J2, J3, J4, J5, J6, J7, J8, J10, J11, J13, J14, J15, J16: Conn_01x01_Male; PinHeader_1x01_P2.54mm_Horizontal
J9, J12: Conn_01x03_Male; PinHeader_1x03_P2.54mm_Horizontal
R1, R2: 10k; R_0805_2012Metric_Pad1.20x1.40mm_HandSolder
U1, U2: 74LS151; SO-16_3.9x9.9mm_P1.27mm

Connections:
/D0: J1.1, U1.4 (I0), U2.4 (I0)
/D1: J2.1, U1.3 (I1), U2.3 (I1)
/D2: J3.1, U1.2 (I2), U2.2 (I2)
/D3: J4.1, U1.1 (I3), U2.1 (I3)
/D4: J5.1, U1.15 (I4), U2.15 (I4)
/D5: J6.1, U1.14 (I5), U2.14 (I5)
/D6: J7.1, U1.13 (I6), U2.13 (I6)
/D7: J8.1, U1.12 (I7), U2.12 (I7)
/O0: J11.1, U1.5 (Z)
/O1: J14.1, U2.5 (Z)
/S0.0: J9.1, U1.11 (S0)
/S0.1: J9.2, U1.10 (S1)
/S0.2: J9.3, U1.9 (S2)
/S1.0: J12.1, U2.11 (S0)
/S1.1: J12.2, U2.10 (S1)
/S1.2: J12.3, U2.9 (S2)
/~E0: J10.1, R1.1, U1.7 (~E)
/~E1: J13.1, R2.1, U2.7 (~E)
GND: C1.2, C2.2, J16.1, R1.2, R2.2, U1.8 (GND), U2.8 (GND)
VCC: C1.1, C2.1, J15.1, U1.16 (VCC), U2.16 (VCC)

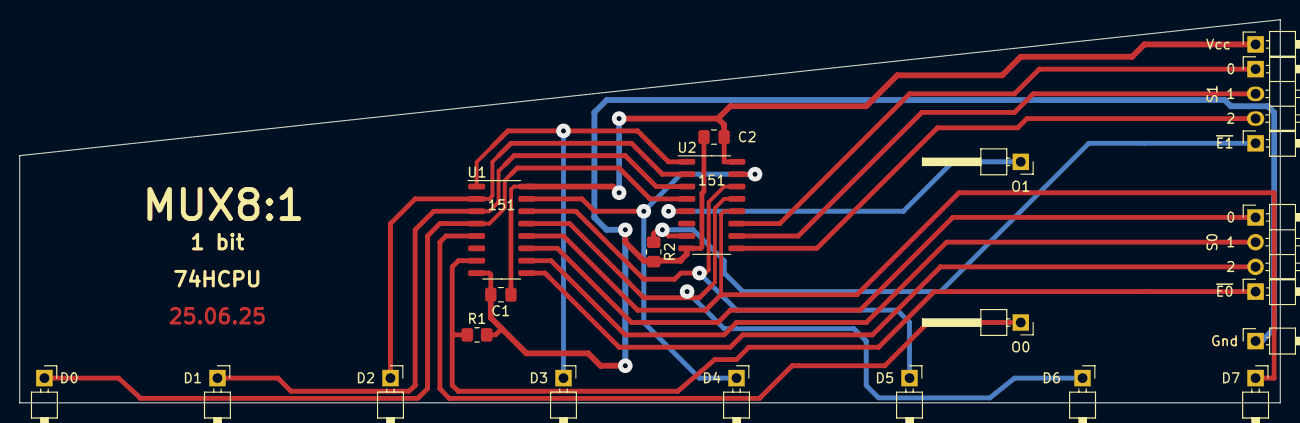
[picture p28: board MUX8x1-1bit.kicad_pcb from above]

Board: 2 copper layers, 129.5 x 39.4 mm, 22 parts (0 on the bottom side), 20 nets.

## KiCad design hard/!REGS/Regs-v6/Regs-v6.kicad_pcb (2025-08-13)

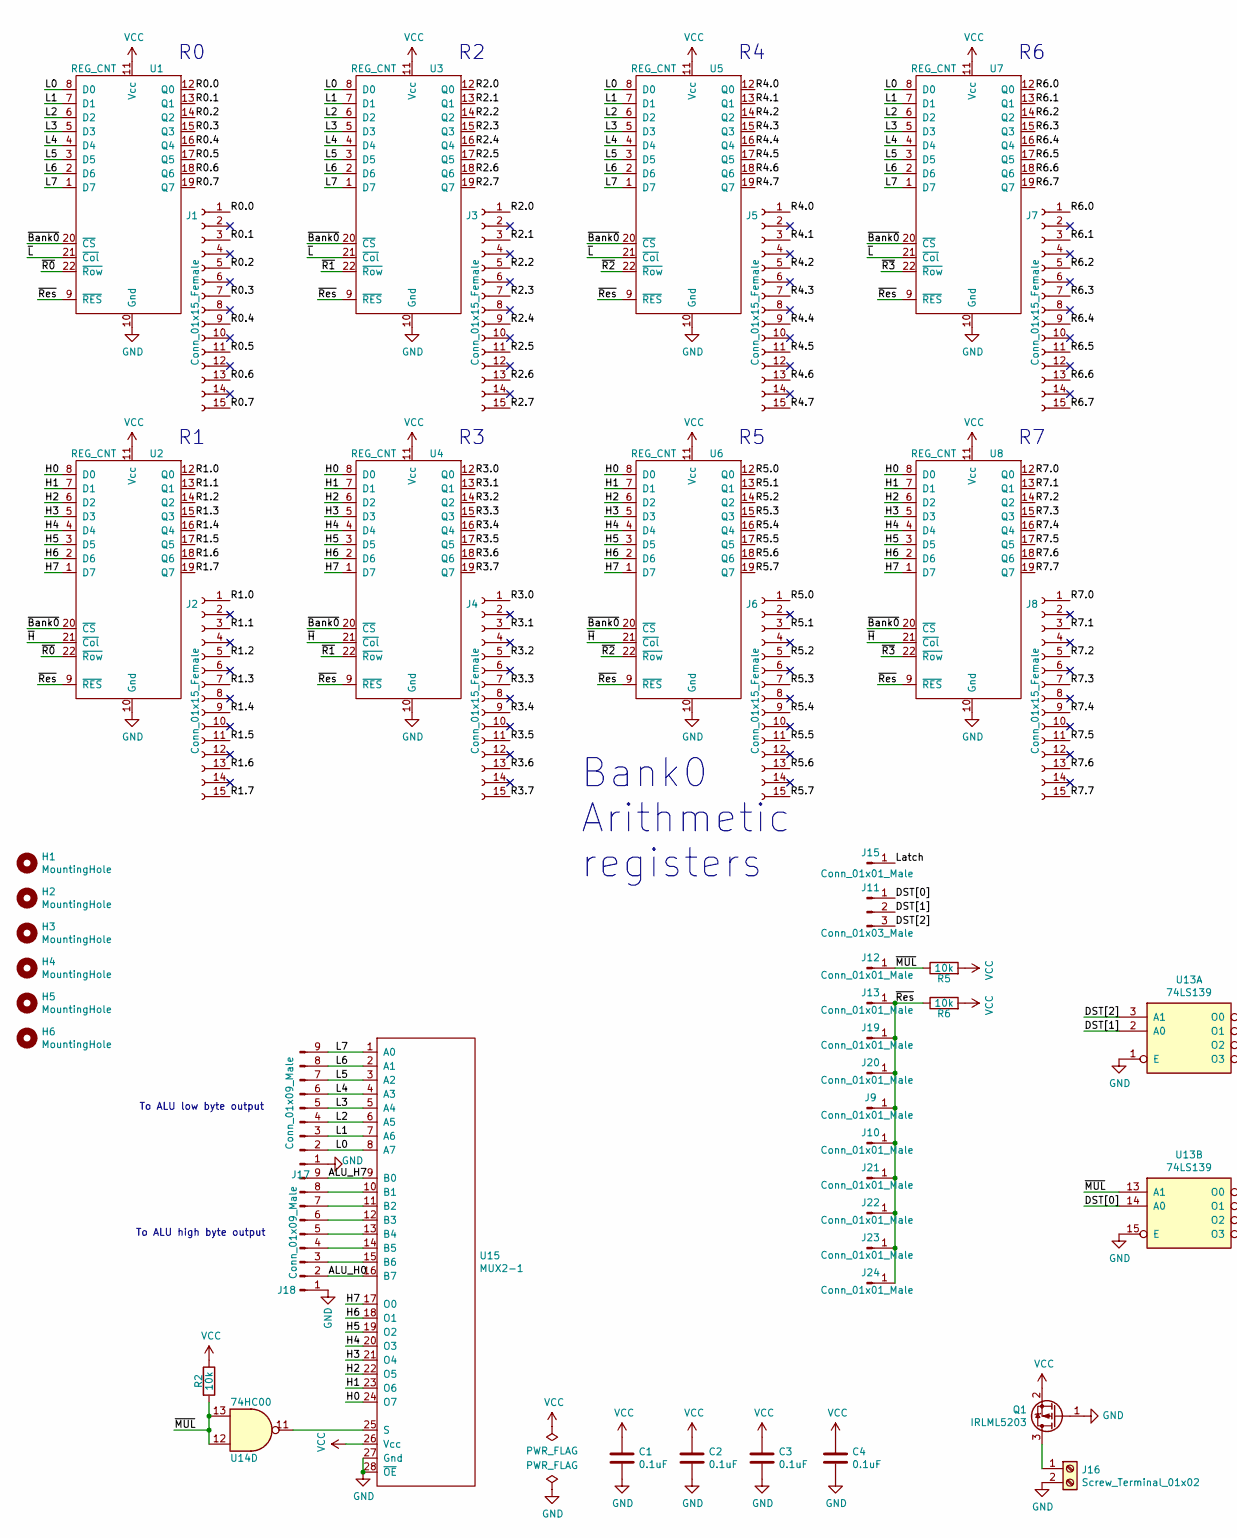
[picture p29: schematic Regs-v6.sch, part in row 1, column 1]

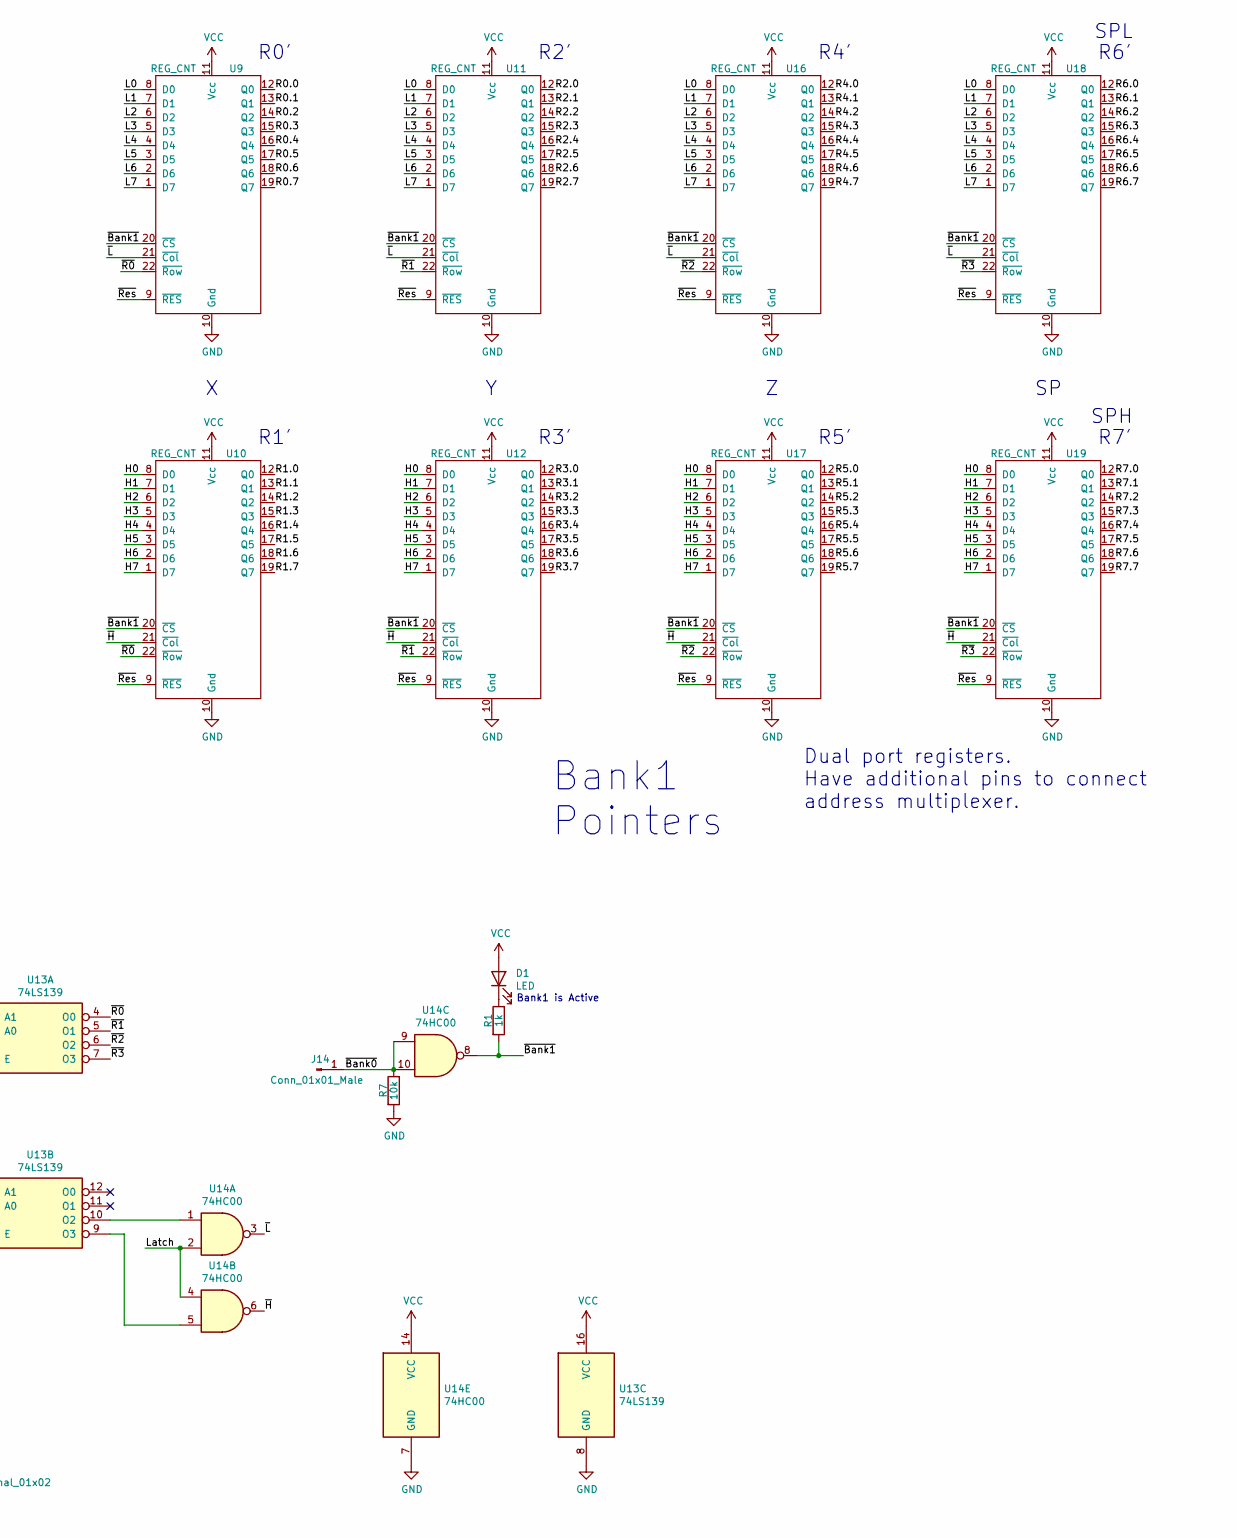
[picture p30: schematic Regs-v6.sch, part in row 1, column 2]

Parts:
C1, C2, C3, C4: 0.1uF; C_0805_2012Metric_Pad1.18x1.45mm_HandSolder
D1: LED; LED_D5.0mm
H1, H2, H3, H4, H5, H6: MountingHole; MountingHole_3.2mm_M3
J1, J2, J3, J4, J5, J6, J7, J8: Conn_01x15_Female; PinSocket_1x15_P2.54mm_Vertical
J9, J10, J12, J13, J14, J15, J19, J20, J21, J22, J23, J24: Conn_01x01_Male; PinHeader_1x01_P2.54mm_Vertical
J11: Conn_01x03_Male; PinHeader_1x03_P2.54mm_Vertical
J16: Screw_Terminal_01x02; TerminalBlock_Phoenix_MKDS-1,5-2_1x02_P5.00mm_Horizontal
J17, J18: Conn_01x09_Male; PinHeader_1x09_P2.54mm_Vertical
Q1: IRLML5203; SOT-23
R1: 1k; R_0805_2012Metric_Pad1.20x1.40mm_HandSolder
R2, R5, R6, R7: 10k; R_0805_2012Metric_Pad1.20x1.40mm_HandSolder
U1, U2, U3, U4, U5, U6, U7, U8, U9, U10, U11, U12, U16, U17, U18, U19: REG_CNT
U13: 74LS139; DIP-16_W7.62mm_Socket
U14: 74HC00; DIP-14_W7.62mm_Socket
U15: MUX2-1; CMDwoC

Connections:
/ALU_H0: J18.2, U15.16 (B7)
/ALU_H7: J18.9, U15.9 (B0)
/DST[0]: J11.1, U13.14 (A0)
/DST[1]: J11.2, U13.2 (A0)
/DST[2]: J11.3, U13.3 (A1)
/H0: U2.8 (D0), U4.8 (D0), U6.8 (D0), U8.8 (D0), U10.8 (D0), U12.8 (D0), U15.24 (O7), U17.8 (D0), U19.8 (D0)
/H1: U2.7 (D1), U4.7 (D1), U6.7 (D1), U8.7 (D1), U10.7 (D1), U12.7 (D1), U15.23 (O6), U17.7 (D1), U19.7 (D1)
/H2: U2.6 (D2), U4.6 (D2), U6.6 (D2), U8.6 (D2), U10.6 (D2), U12.6 (D2), U15.22 (O5), U17.6 (D2), U19.6 (D2)
/H3: U2.5 (D3), U4.5 (D3), U6.5 (D3), U8.5 (D3), U10.5 (D3), U12.5 (D3), U15.21 (O4), U17.5 (D3), U19.5 (D3)
/H4: U2.4 (D4), U4.4 (D4), U6.4 (D4), U8.4 (D4), U10.4 (D4), U12.4 (D4), U15.20 (O3), U17.4 (D4), U19.4 (D4)
/H5: U2.3 (D5), U4.3 (D5), U6.3 (D5), U8.3 (D5), U10.3 (D5), U12.3 (D5), U15.19 (O2), U17.3 (D5), U19.3 (D5)
/H6: U2.2 (D6), U4.2 (D6), U6.2 (D6), U8.2 (D6), U10.2 (D6), U12.2 (D6), U15.18 (O1), U17.2 (D6), U19.2 (D6)
/H7: U2.1 (D7), U4.1 (D7), U6.1 (D7), U8.1 (D7), U10.1 (D7), U12.1 (D7), U15.17 (O0), U17.1 (D7), U19.1 (D7)
/L0: J17.2, U1.8 (D0), U3.8 (D0), U5.8 (D0), U7.8 (D0), U9.8 (D0), U11.8 (D0), U15.8 (A7), U16.8 (D0), U18.8 (D0)
/L1: J17.3, U1.7 (D1), U3.7 (D1), U5.7 (D1), U7.7 (D1), U9.7 (D1), U11.7 (D1), U15.7 (A6), U16.7 (D1), U18.7 (D1)
/L2: J17.4, U1.6 (D2), U3.6 (D2), U5.6 (D2), U7.6 (D2), U9.6 (D2), U11.6 (D2), U15.6 (A5), U16.6 (D2), U18.6 (D2)
/L3: J17.5, U1.5 (D3), U3.5 (D3), U5.5 (D3), U7.5 (D3), U9.5 (D3), U11.5 (D3), U15.5 (A4), U16.5 (D3), U18.5 (D3)
/L4: J17.6, U1.4 (D4), U3.4 (D4), U5.4 (D4), U7.4 (D4), U9.4 (D4), U11.4 (D4), U15.4 (A3), U16.4 (D4), U18.4 (D4)
/L5: J17.7, U1.3 (D5), U3.3 (D5), U5.3 (D5), U7.3 (D5), U9.3 (D5), U11.3 (D5), U15.3 (A2), U16.3 (D5), U18.3 (D5)
/L6: J17.8, U1.2 (D6), U3.2 (D6), U5.2 (D6), U7.2 (D6), U9.2 (D6), U11.2 (D6), U15.2 (A1), U16.2 (D6), U18.2 (D6)
/L7: J17.9, U1.1 (D7), U3.1 (D7), U5.1 (D7), U7.1 (D7), U9.1 (D7), U11.1 (D7), U15.1 (A0), U16.1 (D7), U18.1 (D7)
/Latch: J15.1, U14.2, U14.4
/R0.0: J1.1, U1.12 (Q0), U9.12 (Q0)
/R0.1: J1.3, U1.13 (Q1), U9.13 (Q1)
/R0.2: J1.5, U1.14 (Q2), U9.14 (Q2)
/R0.3: J1.7, U1.15 (Q3), U9.15 (Q3)
/R0.4: J1.9, U1.16 (Q4), U9.16 (Q4)
/R0.5: J1.11, U1.17 (Q5), U9.17 (Q5)
/R0.6: J1.13, U1.18 (Q6), U9.18 (Q6)
/R0.7: J1.15, U1.19 (Q7), U9.19 (Q7)
/R1.0: J2.1, U2.12 (Q0), U10.12 (Q0)
/R1.1: J2.3, U2.13 (Q1), U10.13 (Q1)
/R1.2: J2.5, U2.14 (Q2), U10.14 (Q2)
/R1.3: J2.7, U2.15 (Q3), U10.15 (Q3)
/R1.4: J2.9, U2.16 (Q4), U10.16 (Q4)
/R1.5: J2.11, U2.17 (Q5), U10.17 (Q5)
/R1.6: J2.13, U2.18 (Q6), U10.18 (Q6)
/R1.7: J2.15, U2.19 (Q7), U10.19 (Q7)
/R2.0: J3.1, U3.12 (Q0), U11.12 (Q0)
/R2.1: J3.3, U3.13 (Q1), U11.13 (Q1)
/R2.2: J3.5, U3.14 (Q2), U11.14 (Q2)
/R2.3: J3.7, U3.15 (Q3), U11.15 (Q3)
/R2.4: J3.9, U3.16 (Q4), U11.16 (Q4)
/R2.5: J3.11, U3.17 (Q5), U11.17 (Q5)
/R2.6: J3.13, U3.18 (Q6), U11.18 (Q6)
/R2.7: J3.15, U3.19 (Q7), U11.19 (Q7)
/R3.0: J4.1, U4.12 (Q0), U12.12 (Q0)
/R3.1: J4.3, U4.13 (Q1), U12.13 (Q1)
/R3.2: J4.5, U4.14 (Q2), U12.14 (Q2)
/R3.3: J4.7, U4.15 (Q3), U12.15 (Q3)
/R3.4: J4.9, U4.16 (Q4), U12.16 (Q4)
/R3.5: J4.11, U4.17 (Q5), U12.17 (Q5)
/R3.6: J4.13, U4.18 (Q6), U12.18 (Q6)
/R3.7: J4.15, U4.19 (Q7), U12.19 (Q7)
/R4.0: J5.1, U5.12 (Q0), U16.12 (Q0)
/R4.1: J5.3, U5.13 (Q1), U16.13 (Q1)
/R4.2: J5.5, U5.14 (Q2), U16.14 (Q2)
/R4.3: J5.7, U5.15 (Q3), U16.15 (Q3)
/R4.4: J5.9, U5.16 (Q4), U16.16 (Q4)
/R4.5: J5.11, U5.17 (Q5), U16.17 (Q5)
/R4.6: J5.13, U5.18 (Q6), U16.18 (Q6)
/R4.7: J5.15, U5.19 (Q7), U16.19 (Q7)
/R5.0: J6.1, U6.12 (Q0), U17.12 (Q0)
/R5.1: J6.3, U6.13 (Q1), U17.13 (Q1)
/R5.2: J6.5, U6.14 (Q2), U17.14 (Q2)
/R5.3: J6.7, U6.15 (Q3), U17.15 (Q3)
/R5.4: J6.9, U6.16 (Q4), U17.16 (Q4)
/R5.5: J6.11, U6.17 (Q5), U17.17 (Q5)
/R5.6: J6.13, U6.18 (Q6), U17.18 (Q6)
/R5.7: J6.15, U6.19 (Q7), U17.19 (Q7)
/R6.0: J7.1, U7.12 (Q0), U18.12 (Q0)
/R6.1: J7.3, U7.13 (Q1), U18.13 (Q1)
/R6.2: J7.5, U7.14 (Q2), U18.14 (Q2)
/R6.3: J7.7, U7.15 (Q3), U18.15 (Q3)
/R6.4: J7.9, U7.16 (Q4), U18.16 (Q4)
/R6.5: J7.11, U7.17 (Q5), U18.17 (Q5)
/R6.6: J7.13, U7.18 (Q6), U18.18 (Q6)
/R6.7: J7.15, U7.19 (Q7), U18.19 (Q7)
/R7.0: J8.1, U8.12 (Q0), U19.12 (Q0)
/R7.1: J8.3, U8.13 (Q1), U19.13 (Q1)
/R7.2: J8.5, U8.14 (Q2), U19.14 (Q2)
/R7.3: J8.7, U8.15 (Q3), U19.15 (Q3)
/R7.4: J8.9, U8.16 (Q4), U19.16 (Q4)
/R7.5: J8.11, U8.17 (Q5), U19.17 (Q5)
/R7.6: J8.13, U8.18 (Q6), U19.18 (Q6)
/R7.7: J8.15, U8.19 (Q7), U19.19 (Q7)
/~Bank0: J14.1, R7.1, U1.20 (~CS), U2.20 (~CS), U3.20 (~CS), U4.20 (~CS), U5.20 (~CS), U6.20 (~CS), U7.20 (~CS), U8.20 (~CS), U14.9, U14.10
/~Bank1: R1.2, U9.20 (~CS), U10.20 (~CS), U11.20 (~CS), U12.20 (~CS), U14.8, U16.20 (~CS), U17.20 (~CS), U18.20 (~CS), U19.20 (~CS)
/~H: U2.21 (~Col), U4.21 (~Col), U6.21 (~Col), U8.21 (~Col), U10.21 (~Col), U12.21 (~Col), U14.6, U17.21 (~Col), U19.21 (~Col)
/~L: U1.21 (~Col), U3.21 (~Col), U5.21 (~Col), U7.21 (~Col), U9.21 (~Col), U11.21 (~Col), U14.3, U16.21 (~Col), U18.21 (~Col)
/~MUL: J12.1, R2.2, R5.1, U13.13 (A1), U14.12, U14.13
/~R0: U1.22 (~Row), U2.22 (~Row), U9.22 (~Row), U10.22 (~Row), U13.4 (O0)
/~R1: U3.22 (~Row), U4.22 (~Row), U11.22 (~Row), U12.22 (~Row), U13.5 (O1)
/~R2: U5.22 (~Row), U6.22 (~Row), U13.6 (O2), U16.22 (~Row), U17.22 (~Row)
/~R3: U7.22 (~Row), U8.22 (~Row), U13.7 (O3), U18.22 (~Row), U19.22 (~Row)
/~Res: J9.1, J10.1, J13.1, J19.1, J20.1, J21.1, J22.1, J23.1, J24.1, R6.1, U1.9 (~RES), U2.9 (~RES), U3.9 (~RES), U4.9 (~RES), U5.9 (~RES), U6.9 (~RES), U7.9 (~RES), U8.9 (~RES), U9.9 (~RES), U10.9 (~RES), U11.9 (~RES), U12.9 (~RES), U16.9 (~RES), U17.9 (~RES), U18.9 (~RES), U19.9 (~RES)
GND: C1.2, C2.2, C3.2, C4.2, J16.2, J17.1, J18.1, Q1.1 (G), R7.2, U1.10 (Gnd), U2.10 (Gnd), U3.10 (Gnd), U4.10 (Gnd), U5.10 (Gnd), U6.10 (Gnd), U7.10 (Gnd), U8.10 (Gnd), U9.10 (Gnd), U10.10 (Gnd), U11.10 (Gnd), U12.10 (Gnd), U13.1 (E), U13.8 (GND), U13.15 (E), U14.7 (GND), U15.27 (Gnd), U15.28 (~OE), U16.10 (Gnd), U17.10 (Gnd), U18.10 (Gnd), U19.10 (Gnd)
unnamed: D1.1 (K), R1.1
unnamed: J16.1, Q1.3 (D)
unnamed: J18.3, U15.15 (B6)
unnamed: J18.4, U15.14 (B5)
unnamed: J18.5, U15.13 (B4)
unnamed: J18.6, U15.12 (B3)
unnamed: J18.7, U15.11 (B2)
unnamed: J18.8, U15.10 (B1)
unnamed: U13.9 (O3), U14.5
unnamed: U13.10 (O2), U14.1
unnamed: U14.11, U15.25 (S)
VCC: C1.1, C2.1, C3.1, C4.1, D1.2 (A), Q1.2 (S), R2.1, R5.2, R6.2, U1.11 (Vcc), U2.11 (Vcc), U3.11 (Vcc), U4.11 (Vcc), U5.11 (Vcc), U6.11 (Vcc), U7.11 (Vcc), U8.11 (Vcc), U9.11 (Vcc), U10.11 (Vcc), U11.11 (Vcc), U12.11 (Vcc), U13.16 (VCC), U14.14 (VCC), U15.26 (Vcc), U16.11 (Vcc), U17.11 (Vcc), U18.11 (Vcc), U19.11 (Vcc)

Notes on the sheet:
SPL
SPH
To ALU low byte output
To ALU high byte output
R0'
R4'
R2'
R6'
R7'
R5'
R3'
R1'
Bank0 Arithmetic registers
Bank1 Pointers
Dual port registers. Have additional pins to connect address multiplexer.
Bank1 is Active

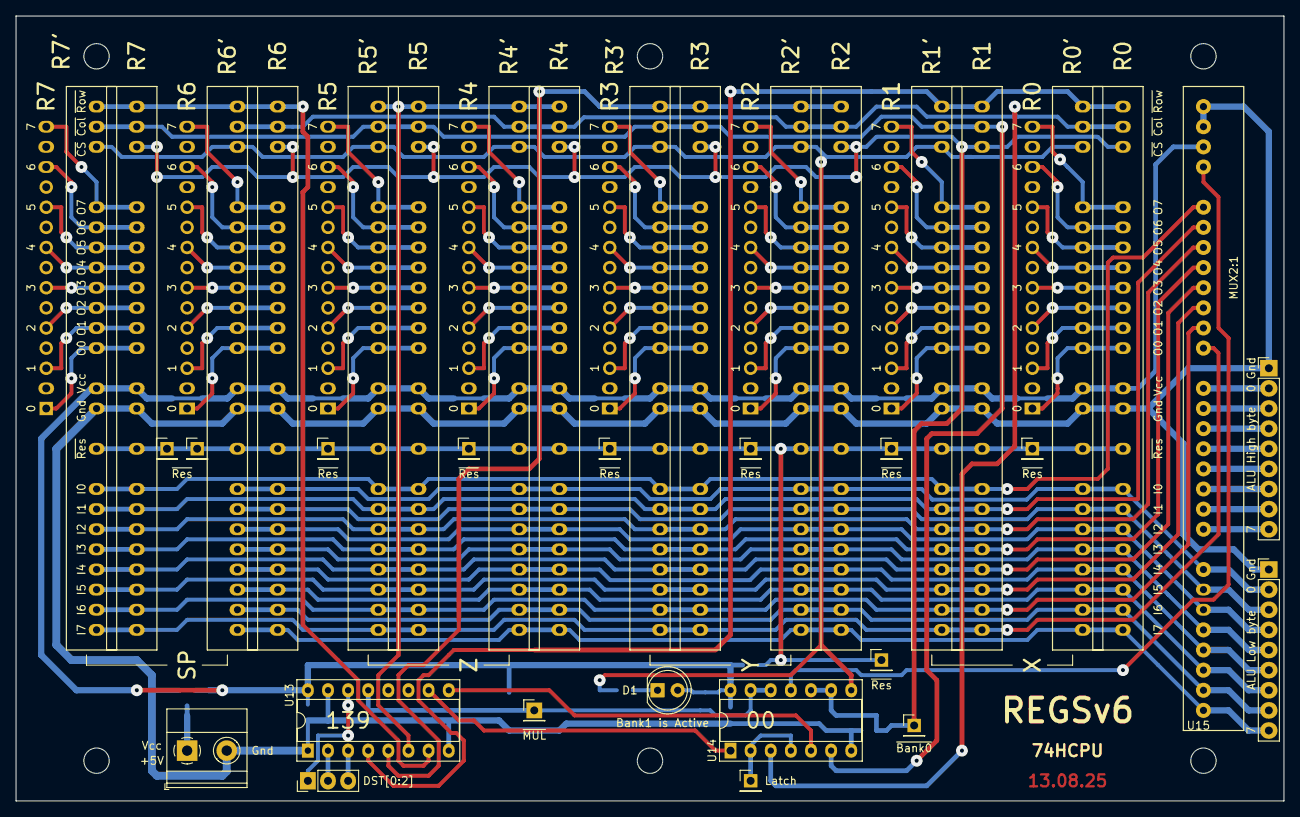
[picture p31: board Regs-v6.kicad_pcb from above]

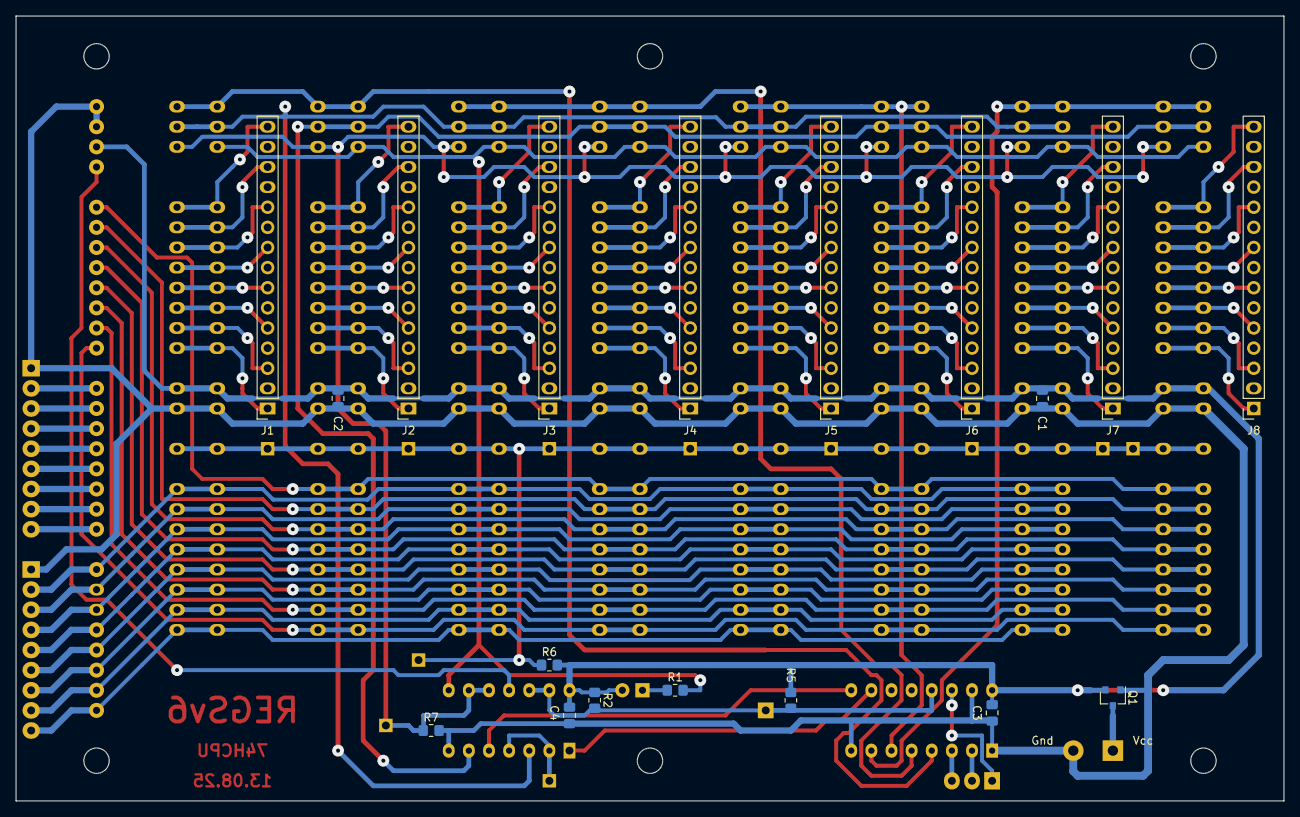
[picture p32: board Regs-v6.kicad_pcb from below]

Board: 2 copper layers, 160.0 x 99.1 mm, 60 parts (18 on the bottom side), 109 nets.

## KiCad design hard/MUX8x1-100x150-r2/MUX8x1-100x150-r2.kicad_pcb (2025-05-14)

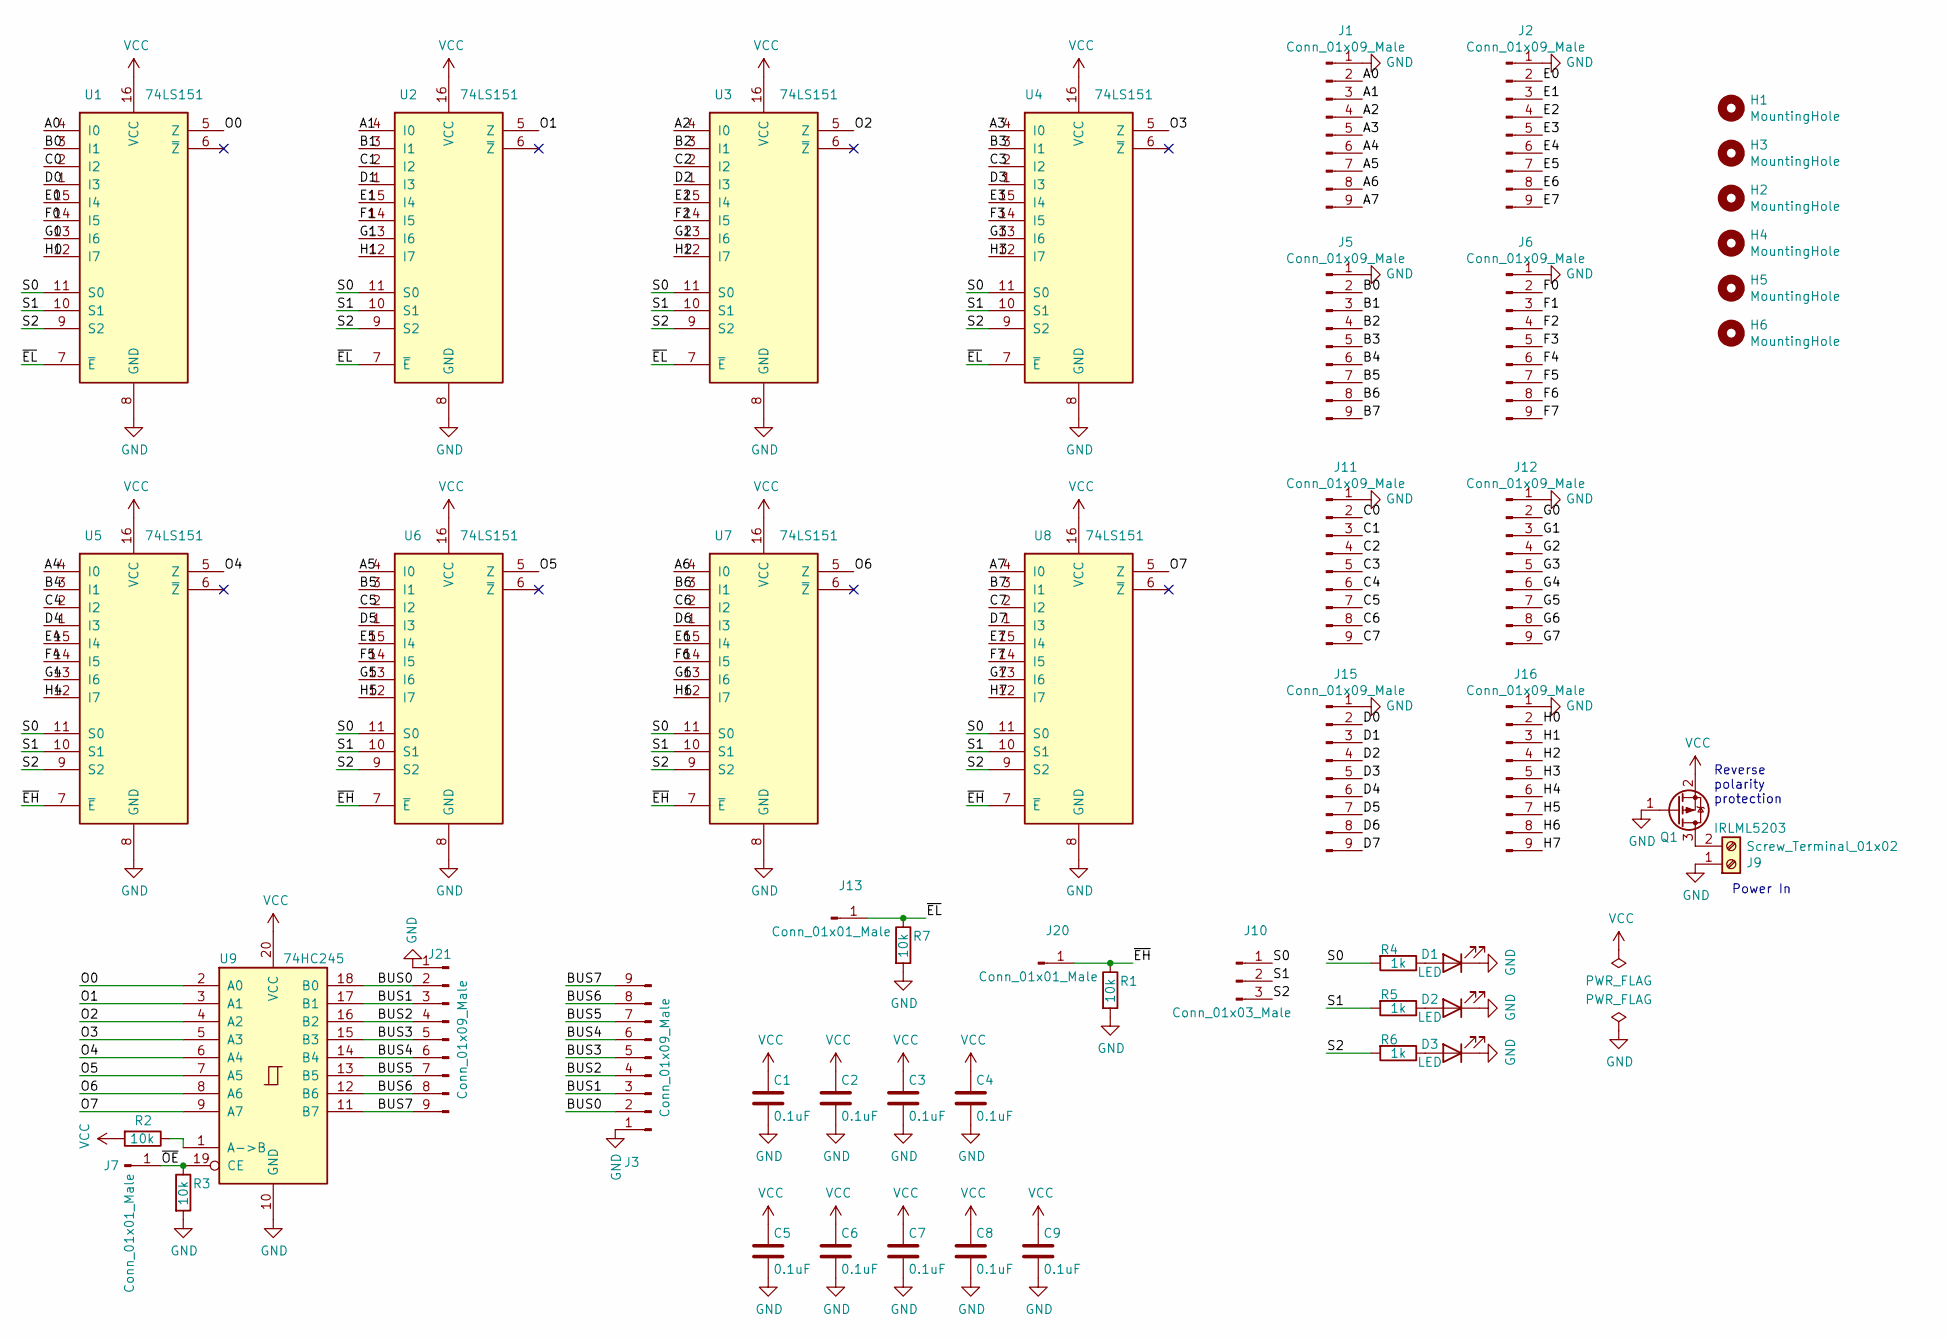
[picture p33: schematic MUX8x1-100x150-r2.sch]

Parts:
C1, C2, C3, C4, C5, C6, C7, C8, C9: 0.1uF; C_Axial_L3.8mm_D2.6mm_P12.50mm_Horizontal
D1, D2, D3: LED; LED_0805_2012Metric_Pad1.15x1.40mm_HandSolder
H1, H2, H3, H4, H5, H6: MountingHole; MountingHole_3.2mm_M3
J1, J2, J3, J5, J6, J11, J12, J15, J16, J21: Conn_01x09_Male; PinHeader_1x09_P2.54mm_Vertical
J7, J13, J20: Conn_01x01_Male; PinHeader_1x01_P2.54mm_Vertical
J9: Screw_Terminal_01x02; TerminalBlock_Phoenix_MKDS-1,5-2_1x02_P5.00mm_Horizontal
J10: Conn_01x03_Male; PinHeader_1x03_P2.54mm_Vertical
Q1: IRLML5203; SOT-23
R1, R2, R3, R7: 10k; R_0805_2012Metric_Pad1.20x1.40mm_HandSolder
R4, R5, R6: 1k; R_0805_2012Metric_Pad1.20x1.40mm_HandSolder
U1, U2, U3, U4, U5, U6, U7, U8: 74LS151; DIP-16_W7.62mm_Socket
U9: 74HC245; DIP-20_W7.62mm_Socket

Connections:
/A0: J1.2, U1.4 (I0)
/A1: J1.3, U2.4 (I0)
/A2: J1.4, U3.4 (I0)
/A3: J1.5, U4.4 (I0)
/A4: J1.6, U5.4 (I0)
/A5: J1.7, U6.4 (I0)
/A6: J1.8, U7.4 (I0)
/A7: J1.9, U8.4 (I0)
/B0: J5.2, U1.3 (I1)
/B1: J5.3, U2.3 (I1)
/B2: J5.4, U3.3 (I1)
/B3: J5.5, U4.3 (I1)
/B4: J5.6, U5.3 (I1)
/B5: J5.7, U6.3 (I1)
/B6: J5.8, U7.3 (I1)
/B7: J5.9, U8.3 (I1)
/BUS0: J3.2, J21.2, U9.18 (B0)
/BUS1: J3.3, J21.3, U9.17 (B1)
/BUS2: J3.4, J21.4, U9.16 (B2)
/BUS3: J3.5, J21.5, U9.15 (B3)
/BUS4: J3.6, J21.6, U9.14 (B4)
/BUS5: J3.7, J21.7, U9.13 (B5)
/BUS6: J3.8, J21.8, U9.12 (B6)
/BUS7: J3.9, J21.9, U9.11 (B7)
/C0: J11.2, U1.2 (I2)
/C1: J11.3, U2.2 (I2)
/C2: J11.4, U3.2 (I2)
/C3: J11.5, U4.2 (I2)
/C4: J11.6, U5.2 (I2)
/C5: J11.7, U6.2 (I2)
/C6: J11.8, U7.2 (I2)
/C7: J11.9, U8.2 (I2)
/D0: J15.2, U1.1 (I3)
/D1: J15.3, U2.1 (I3)
/D2: J15.4, U3.1 (I3)
/D3: J15.5, U4.1 (I3)
/D4: J15.6, U5.1 (I3)
/D5: J15.7, U6.1 (I3)
/D6: J15.8, U7.1 (I3)
/D7: J15.9, U8.1 (I3)
/E0: J2.2, U1.15 (I4)
/E1: J2.3, U2.15 (I4)
/E2: J2.4, U3.15 (I4)
/E3: J2.5, U4.15 (I4)
/E4: J2.6, U5.15 (I4)
/E5: J2.7, U6.15 (I4)
/E6: J2.8, U7.15 (I4)
/E7: J2.9, U8.15 (I4)
/F0: J6.2, U1.14 (I5)
/F1: J6.3, U2.14 (I5)
/F2: J6.4, U3.14 (I5)
/F3: J6.5, U4.14 (I5)
/F4: J6.6, U5.14 (I5)
/F5: J6.7, U6.14 (I5)
/F6: J6.8, U7.14 (I5)
/F7: J6.9, U8.14 (I5)
/G0: J12.2, U1.13 (I6)
/G1: J12.3, U2.13 (I6)
/G2: J12.4, U3.13 (I6)
/G3: J12.5, U4.13 (I6)
/G4: J12.6, U5.13 (I6)
/G5: J12.7, U6.13 (I6)
/G6: J12.8, U7.13 (I6)
/G7: J12.9, U8.13 (I6)
/H0: J16.2, U1.12 (I7)
/H1: J16.3, U2.12 (I7)
/H2: J16.4, U3.12 (I7)
/H3: J16.5, U4.12 (I7)
/H4: J16.6, U5.12 (I7)
/H5: J16.7, U6.12 (I7)
/H6: J16.8, U7.12 (I7)
/H7: J16.9, U8.12 (I7)
/O0: U1.5 (Z), U9.2 (A0)
/O1: U2.5 (Z), U9.3 (A1)
/O2: U3.5 (Z), U9.4 (A2)
/O3: U4.5 (Z), U9.5 (A3)
/O4: U5.5 (Z), U9.6 (A4)
/O5: U6.5 (Z), U9.7 (A5)
/O6: U7.5 (Z), U9.8 (A6)
/O7: U8.5 (Z), U9.9 (A7)
/S0: J10.1, R4.2, U1.11 (S0), U2.11 (S0), U3.11 (S0), U4.11 (S0), U5.11 (S0), U6.11 (S0), U7.11 (S0), U8.11 (S0)
/S1: J10.2, R5.2, U1.10 (S1), U2.10 (S1), U3.10 (S1), U4.10 (S1), U5.10 (S1), U6.10 (S1), U7.10 (S1), U8.10 (S1)
/S2: J10.3, R6.2, U1.9 (S2), U2.9 (S2), U3.9 (S2), U4.9 (S2), U5.9 (S2), U6.9 (S2), U7.9 (S2), U8.9 (S2)
/~EH: J20.1, R1.1, U5.7 (~E), U6.7 (~E), U7.7 (~E), U8.7 (~E)
/~EL: J13.1, R7.1, U1.7 (~E), U2.7 (~E), U3.7 (~E), U4.7 (~E)
/~OE: J7.1, R3.1, U9.19 (CE)
GND: C1.2, C2.2, C3.2, C4.2, C5.2, C6.2, C7.2, C8.2, C9.2, D1.1 (K), D2.1 (K), D3.1 (K), J1.1, J2.1, J3.1, J5.1, J6.1, J9.1, J11.1, J12.1, J15.1, J16.1, J21.1, Q1.1 (G), R1.2, R3.2, R7.2, U1.8 (GND), U2.8 (GND), U3.8 (GND), U4.8 (GND), U5.8 (GND), U6.8 (GND), U7.8 (GND), U8.8 (GND), U9.10 (GND)
unnamed: D1.2 (A), R4.1
unnamed: D2.2 (A), R5.1
unnamed: D3.2 (A), R6.1
unnamed: J9.2, Q1.3 (D)
unnamed: R2.1, U9.1 (A->B)
VCC: C1.1, C2.1, C3.1, C4.1, C5.1, C6.1, C7.1, C8.1, C9.1, Q1.2 (S), R2.2, U1.16 (VCC), U2.16 (VCC), U3.16 (VCC), U4.16 (VCC), U5.16 (VCC), U6.16 (VCC), U7.16 (VCC), U8.16 (VCC), U9.20 (VCC)

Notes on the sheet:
Power In
Reverse polarity protection

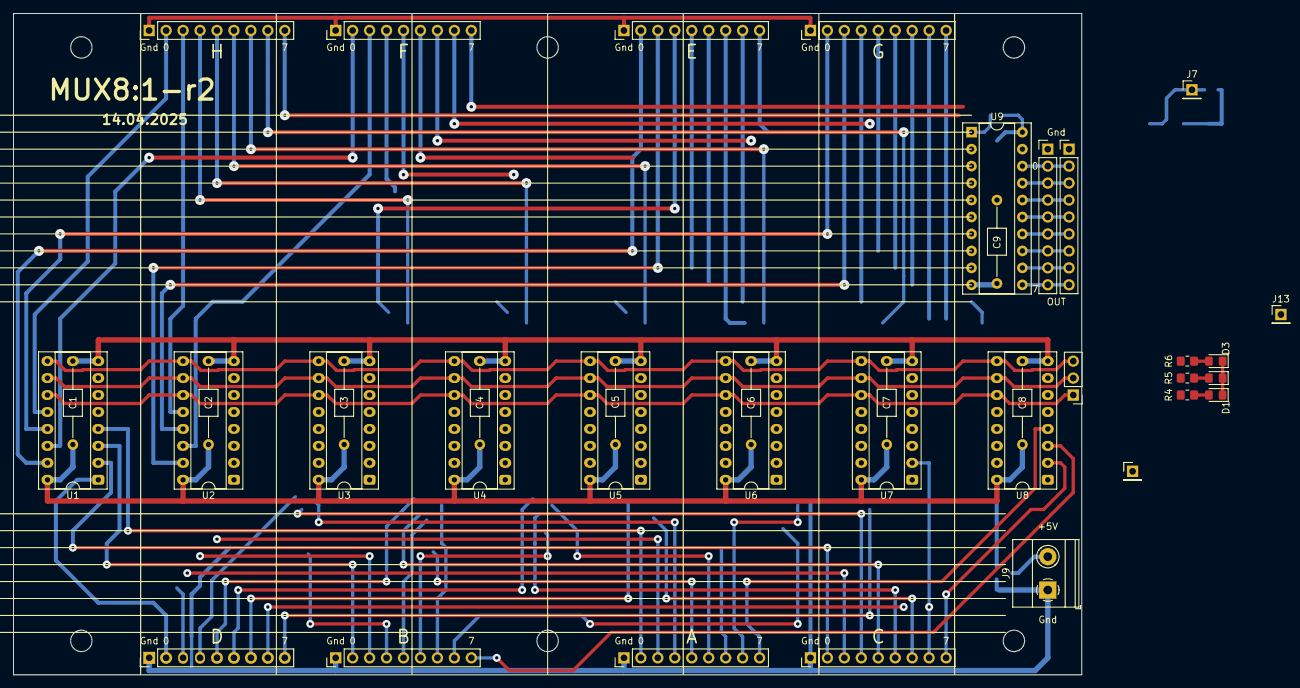
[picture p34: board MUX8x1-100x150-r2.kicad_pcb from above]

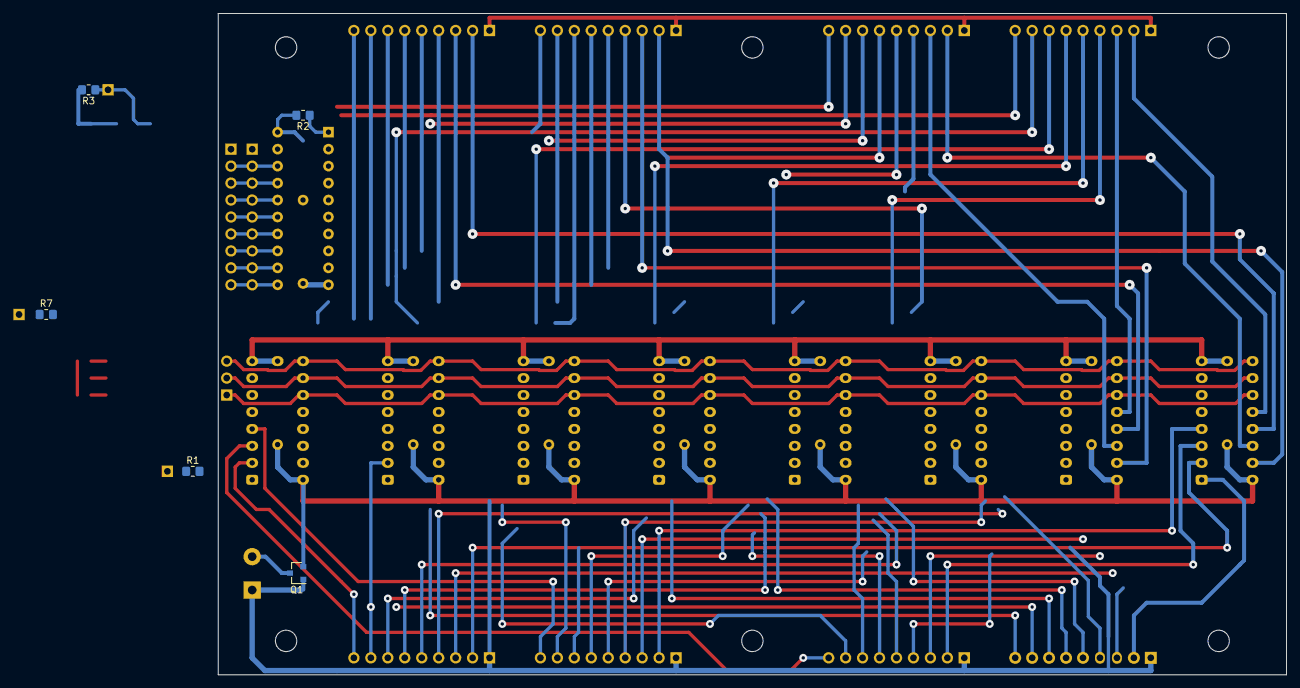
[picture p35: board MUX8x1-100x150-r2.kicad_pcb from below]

Board: 2 copper layers, 160.0 x 99.1 mm, 50 parts (5 on the bottom side), 93 nets.

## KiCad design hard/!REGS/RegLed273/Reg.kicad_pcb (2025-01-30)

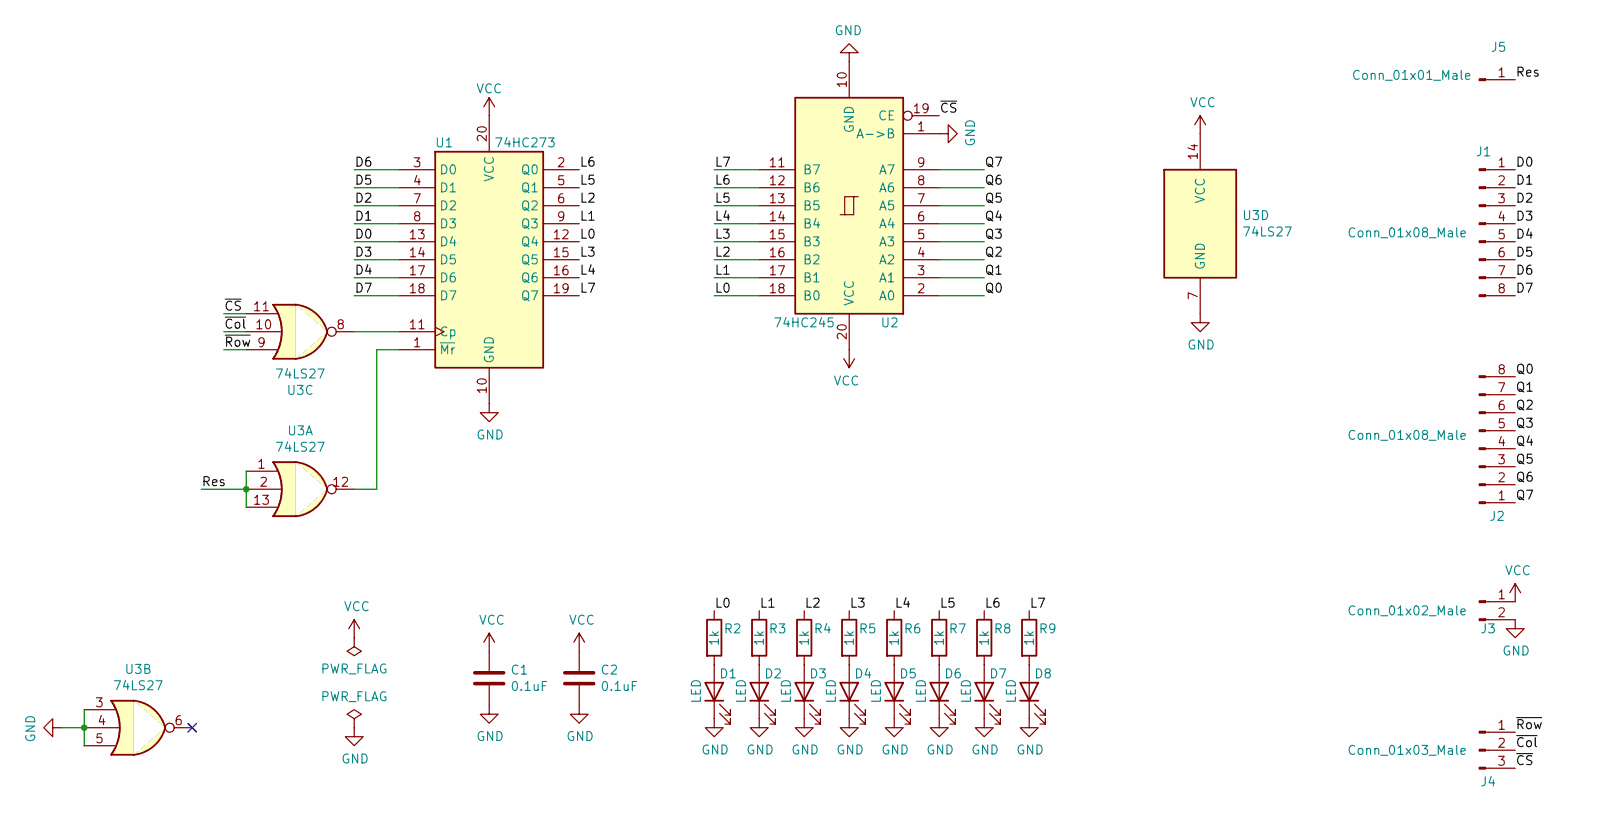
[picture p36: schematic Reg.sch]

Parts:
C1, C2: 0.1uF; C_0805_2012Metric_Pad1.18x1.45mm_HandSolder
D1, D2, D3, D4, D5, D6, D7, D8: LED; LED_0805_2012Metric_Pad1.15x1.40mm_HandSolder
J1, J2: Conn_01x08_Male; PinHeader_1x08_P2.54mm_Horizontal
J3: Conn_01x02_Male; PinHeader_1x02_P2.54mm_Horizontal
J4: Conn_01x03_Male; PinHeader_1x03_P2.54mm_Horizontal
J5: Conn_01x01_Male; PinHeader_1x01_P2.54mm_Horizontal
R2, R3, R4, R5, R6, R7, R8, R9: 1k; R_0805_2012Metric_Pad1.20x1.40mm_HandSolder
U1: 74HC273; DIP-20_W7.62mm
U2: 74HC245; DIP-20_W7.62mm
U3: 74LS27; SO-14_3.9x8.65mm_P1.27mm

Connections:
/D0: J1.1, U1.13 (D4)
/D1: J1.2, U1.8 (D3)
/D2: J1.3, U1.7 (D2)
/D3: J1.4, U1.14 (D5)
/D4: J1.5, U1.17 (D6)
/D5: J1.6, U1.4 (D1)
/D6: J1.7, U1.3 (D0)
/D7: J1.8, U1.18 (D7)
/L0: R2.1, U1.12 (Q4), U2.18 (B0)
/L1: R3.1, U1.9 (Q3), U2.17 (B1)
/L2: R4.1, U1.6 (Q2), U2.16 (B2)
/L3: R5.1, U1.15 (Q5), U2.15 (B3)
/L4: R6.1, U1.16 (Q6), U2.14 (B4)
/L5: R7.1, U1.5 (Q1), U2.13 (B5)
/L6: R8.1, U1.2 (Q0), U2.12 (B6)
/L7: R9.1, U1.19 (Q7), U2.11 (B7)
/Q0: J2.8, U2.2 (A0)
/Q1: J2.7, U2.3 (A1)
/Q2: J2.6, U2.4 (A2)
/Q3: J2.5, U2.5 (A3)
/Q4: J2.4, U2.6 (A4)
/Q5: J2.3, U2.7 (A5)
/Q6: J2.2, U2.8 (A6)
/Q7: J2.1, U2.9 (A7)
/Res: J5.1, U3.1, U3.2, U3.13
/~CS: J4.3, U2.19 (CE), U3.11
/~Col: J4.2, U3.10
/~Row: J4.1, U3.9
GND: C1.2, C2.2, D1.1 (K), D2.1 (K), D3.1 (K), D4.1 (K), D5.1 (K), D6.1 (K), D7.1 (K), D8.1 (K), J3.2, U1.10 (GND), U2.1 (A->B), U2.10 (GND), U3.3, U3.4, U3.5, U3.7 (GND)
unnamed: D1.2 (A), R2.2
unnamed: D2.2 (A), R3.2
unnamed: D3.2 (A), R4.2
unnamed: D4.2 (A), R5.2
unnamed: D5.2 (A), R6.2
unnamed: D6.2 (A), R7.2
unnamed: D7.2 (A), R8.2
unnamed: D8.2 (A), R9.2
unnamed: U1.1 (~Mr), U3.12
unnamed: U1.11 (Cp), U3.8
VCC: C1.1, C2.1, J3.1, U1.20 (VCC), U2.20 (VCC), U3.14 (VCC)

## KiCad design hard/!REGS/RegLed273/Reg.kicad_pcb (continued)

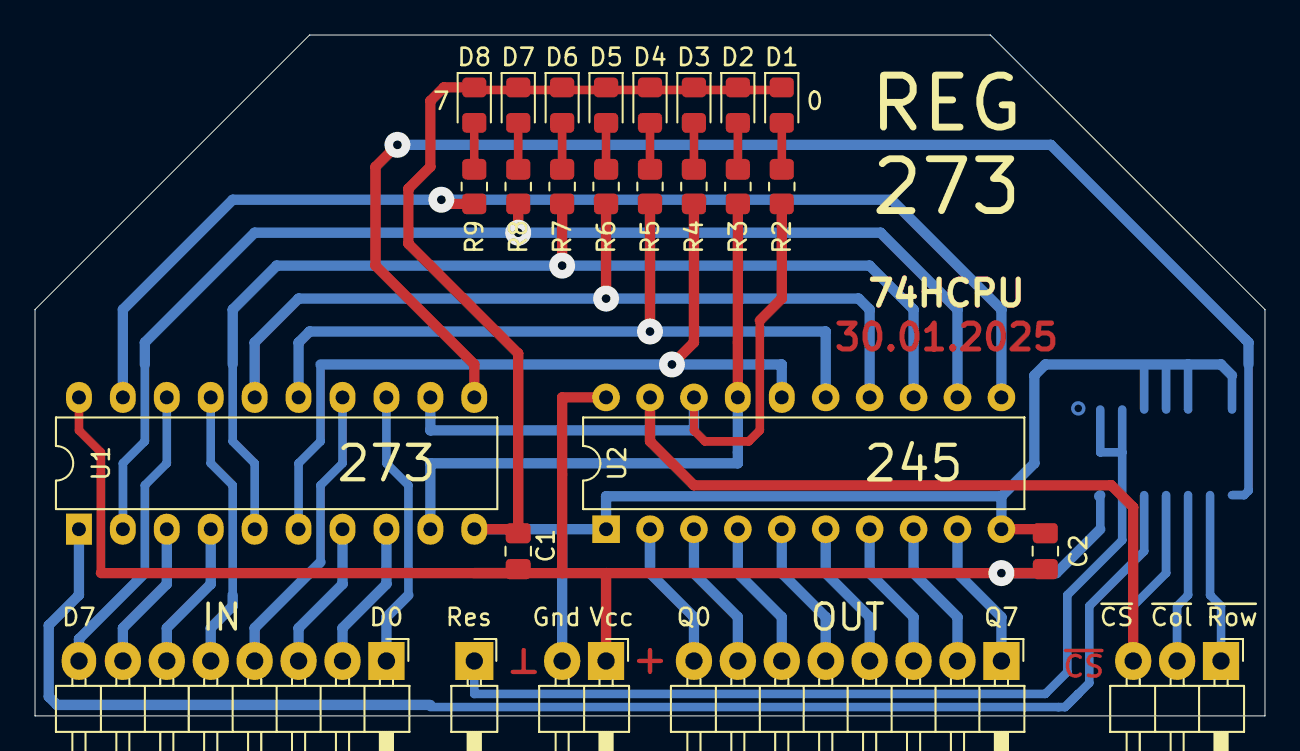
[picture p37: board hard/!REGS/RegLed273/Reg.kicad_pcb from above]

Board: 2 copper layers, 71.1 x 39.4 mm, 26 parts (1 on the bottom side), 40 nets.

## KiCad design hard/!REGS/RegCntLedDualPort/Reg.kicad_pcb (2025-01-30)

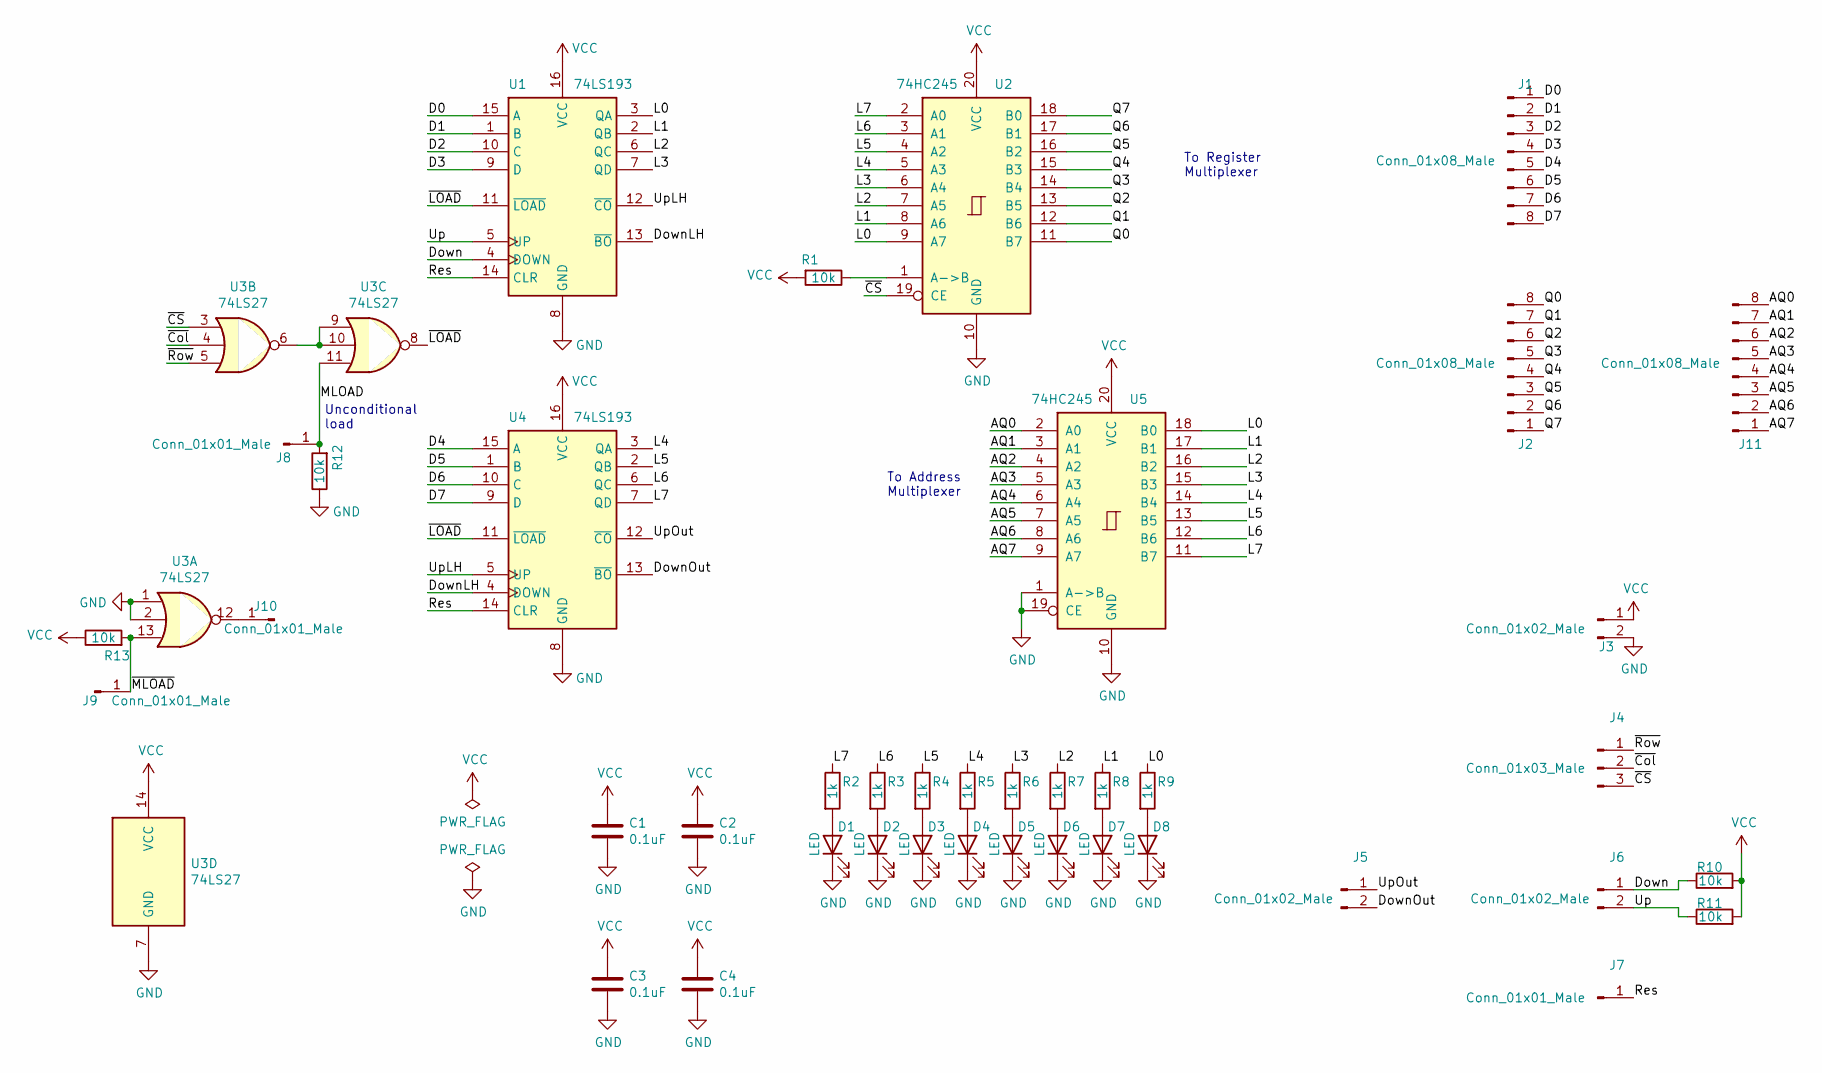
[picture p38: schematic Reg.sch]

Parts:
C1, C3: 0.1uF; C_Axial_L3.8mm_D2.6mm_P12.50mm_Horizontal
C2, C4: 0.1uF; C_0805_2012Metric_Pad1.18x1.45mm_HandSolder
D1, D2, D3, D4, D5, D6, D7, D8: LED; LED_0805_2012Metric_Pad1.15x1.40mm_HandSolder
J1, J2, J11: Conn_01x08_Male; PinHeader_1x08_P2.54mm_Horizontal
J3, J5, J6: Conn_01x02_Male; PinHeader_1x02_P2.54mm_Horizontal
J4: Conn_01x03_Male; PinHeader_1x03_P2.54mm_Horizontal
J7, J8, J9, J10: Conn_01x01_Male; PinHeader_1x01_P2.54mm_Horizontal
R1, R10, R11, R12, R13: 10k; R_0805_2012Metric_Pad1.20x1.40mm_HandSolder
R2, R3, R4, R5, R6, R7, R8, R9: 1k; R_0805_2012Metric_Pad1.20x1.40mm_HandSolder
U1, U4: 74LS193; SOP-16_3.9x9.9mm_P1.27mm
U2, U5: 74HC245; SOP-20_7.5x12.8mm_P1.27mm
U3: 74LS27; SO-14_3.9x8.65mm_P1.27mm

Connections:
/AQ0: J11.8, U5.2 (A0)
/AQ1: J11.7, U5.3 (A1)
/AQ2: J11.6, U5.4 (A2)
/AQ3: J11.5, U5.5 (A3)
/AQ4: J11.4, U5.6 (A4)
/AQ5: J11.3, U5.7 (A5)
/AQ6: J11.2, U5.8 (A6)
/AQ7: J11.1, U5.9 (A7)
/D0: J1.1, U1.15 (A)
/D1: J1.2, U1.1 (B)
/D2: J1.3, U1.10 (C)
/D3: J1.4, U1.9 (D)
/D4: J1.5, U4.15 (A)
/D5: J1.6, U4.1 (B)
/D6: J1.7, U4.10 (C)
/D7: J1.8, U4.9 (D)
/Down: J6.1, R10.1, U1.4 (DOWN)
/DownLH: U1.13 (~BO), U4.4 (DOWN)
/DownOut: J5.2, U4.13 (~BO)
/L0: R9.1, U1.3 (QA), U2.9 (A7), U5.18 (B0)
/L1: R8.1, U1.2 (QB), U2.8 (A6), U5.17 (B1)
/L2: R7.1, U1.6 (QC), U2.7 (A5), U5.16 (B2)
/L3: R6.1, U1.7 (QD), U2.6 (A4), U5.15 (B3)
/L4: R5.1, U2.5 (A3), U4.3 (QA), U5.14 (B4)
/L5: R4.1, U2.4 (A2), U4.2 (QB), U5.13 (B5)
/L6: R3.1, U2.3 (A1), U4.6 (QC), U5.12 (B6)
/L7: R2.1, U2.2 (A0), U4.7 (QD), U5.11 (B7)
/MLOAD: J8.1, R12.2, U3.11
/Q0: J2.8, U2.11 (B7)
/Q1: J2.7, U2.12 (B6)
/Q2: J2.6, U2.13 (B5)
/Q3: J2.5, U2.14 (B4)
/Q4: J2.4, U2.15 (B3)
/Q5: J2.3, U2.16 (B2)
/Q6: J2.2, U2.17 (B1)
/Q7: J2.1, U2.18 (B0)
/Res: J7.1, U1.14 (CLR), U4.14 (CLR)
/Up: J6.2, R11.1, U1.5 (UP)
/UpLH: U1.12 (~CO), U4.5 (UP)
/UpOut: J5.1, U4.12 (~CO)
/~CS: J4.3, U2.19 (CE), U3.3
/~Col: J4.2, U3.4
/~LOAD: U1.11 (~LOAD), U3.8, U4.11 (~LOAD)
/~MLOAD: J9.1, R13.2, U3.13
/~Row: J4.1, U3.5
GND: C1.2, C2.2, C3.2, C4.2, D1.1 (K), D2.1 (K), D3.1 (K), D4.1 (K), D5.1 (K), D6.1 (K), D7.1 (K), D8.1 (K), J3.2, R12.1, U1.8 (GND), U2.10 (GND), U3.1, U3.2, U3.7 (GND), U4.8 (GND), U5.1 (A->B), U5.10 (GND), U5.19 (CE)
unnamed: D1.2 (A), R2.2
unnamed: D2.2 (A), R3.2
unnamed: D3.2 (A), R4.2
unnamed: D4.2 (A), R5.2
unnamed: D5.2 (A), R6.2
unnamed: D6.2 (A), R7.2
unnamed: D7.2 (A), R8.2
unnamed: D8.2 (A), R9.2
unnamed: J10.1, U3.12
unnamed: R1.1, U2.1 (A->B)
unnamed: U3.6, U3.9, U3.10
VCC: C1.1, C2.1, C3.1, C4.1, J3.1, R1.2, R10.2, R11.2, R13.1, U1.16 (VCC), U2.20 (VCC), U3.14 (VCC), U4.16 (VCC), U5.20 (VCC)

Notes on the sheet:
Unconditional load
To Register Multiplexer
To Address Multiplexer



Board: 2 copper layers, 71.1 x 42.5 mm, 41 parts (7 on the bottom side), 58 nets.

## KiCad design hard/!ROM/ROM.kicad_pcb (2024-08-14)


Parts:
BAR1, BAR2: HDSP-4850
C1: 0.1uF; C_Rect_L24.0mm_W7.0mm_P22.50mm_MKT
C2, C3, C4, C5, C6, C7: 0.1uF; C_Disc_D7.5mm_W5.0mm_P7.50mm
H1, H2, H3, H4, H5, H6: MountingHole; MountingHole_3.2mm_M3
J1, J2, J3, J5, J6, J7, J8, J12, J13: Conn_01x09_Male; PinHeader_1x09_P2.54mm_Vertical
J4: Screw_Terminal_01x02; TerminalBlock_Phoenix_PT-1,5-2-5.0-H_1x02_P5.00mm_Horizontal
J9, J10, J11, J14: Conn_01x01_Male; PinHeader_1x01_P2.54mm_Vertical
Q1: IRLML5203; SOT-23
R1, R2, R3, R4, R5, R6: 10K; R_0805_2012Metric_Pad1.20x1.40mm_HandSolder
RN1, RN2, RN3: R_Network08; R_Array_SIP9
U1: AM29F200BB-SO44; DIP-44_W15.24mm
U2, U3: 74LS573; DIP-20_W7.62mm
U4, U5, U7: 74LS245; DIP-20_W7.62mm
U6: 74HC00; DIP-14_W7.62mm

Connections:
/A0: J3.2, U1.11 (A0)
/A1: J3.3, U1.10 (A1)
/A2: J3.4, U1.9 (A2)
/A3: J3.5, U1.8 (A3)
/A4: J3.6, U1.7 (A4)
/A5: J3.7, U1.6 (A5)
/A6: J3.8, U1.5 (A6)
/A7: J3.9, U1.4 (A7)
/A8: J12.2, RN1.2 (R1), U1.42 (A8)
/A9: J12.3, RN1.3 (R2), U1.41 (A9)
/A10: J12.4, RN1.4 (R3), U1.40 (A10)
/A11: J12.5, RN1.5 (R4), U1.39 (A11)
/A12: J12.6, RN1.6 (R5), U1.38 (A12)
/A13: J12.7, RN1.7 (R6), U1.37 (A13)
/A14: J12.8, RN1.8 (R7), U1.36 (A14)
/A15: J12.9, RN1.9 (R8), U1.35 (A15)
/BUS0: J2.2, U5.11 (B7)
/BUS1: J2.3, U5.12 (B6)
/BUS2: J2.4, U5.13 (B5)
/BUS3: J2.5, U5.14 (B4)
/BUS4: J2.6, U5.15 (B3)
/BUS5: J2.7, U5.16 (B2)
/BUS6: J2.8, U5.17 (B1)
/BUS7: J2.9, U5.18 (B0)
/C1: J10.1, U6.1, U6.2
/CNST0: BAR2.10 (A), J7.2, J8.2, J13.2, U4.11 (B7), U5.9 (A7)
/CNST1: BAR2.9 (A), J7.3, J8.3, J13.3, U4.12 (B6), U5.8 (A6)
/CNST2: BAR2.8 (A), J7.4, J8.4, J13.4, U4.13 (B5), U5.7 (A5)
/CNST3: BAR2.7 (A), J7.5, J8.5, J13.5, U4.14 (B4), U5.6 (A4)
/CNST4: BAR2.6 (A), J7.6, J8.6, J13.6, U4.15 (B3), U5.5 (A3)
/CNST5: BAR2.5 (A), J7.7, J8.7, J13.7, U4.16 (B2), U5.4 (A2)
/CNST6: BAR2.4 (A), J7.8, J8.8, J13.8, U4.17 (B1), U5.3 (A1)
/CNST7: BAR2.3 (A), J7.9, J8.9, J13.9, U4.18 (B0), U5.2 (A0)
/COP0: BAR1.10 (A), J1.2, J5.2, J6.2, U7.11 (B7)
/COP1: BAR1.9 (A), J1.3, J5.3, J6.3, U7.12 (B6)
/COP2: BAR1.8 (A), J1.4, J5.4, J6.4, U7.13 (B5)
/COP3: BAR1.7 (A), J1.5, J5.5, J6.5, U7.14 (B4)
/COP4: BAR1.6 (A), J1.6, J5.6, J6.6, U7.15 (B3)
/COP5: BAR1.5 (A), J1.7, J5.7, J6.7, U7.16 (B2)
/COP6: BAR1.4 (A), J1.8, J5.8, J6.8, U7.17 (B1)
/COP7: BAR1.3 (A), J1.9, J5.9, J6.9, U7.18 (B0)
/D0: U1.15 (D0), U2.9 (D7)
/D1: U1.17 (D1), U2.8 (D6)
/D2: U1.19 (D2), U2.7 (D5)
/D3: U1.21 (D3), U2.6 (D4)
/D4: U1.24 (D4), U2.5 (D3)
/D5: U1.26 (D5), U2.4 (D2)
/D6: U1.28 (D6), U2.3 (D1)
/D7: U1.30 (D7), U2.2 (D0)
/D8: U1.16 (D8), U3.9 (D7)
/D9: U1.18 (D9), U3.8 (D6)
/D10: U1.20 (D10), U3.7 (D5)
/D11: U1.22 (D11), U3.6 (D4)
/D12: U1.25 (D12), U3.5 (D3)
/D13: U1.27 (D13), U3.4 (D2)
/D14: U1.29 (D14), U3.3 (D1)
/D15: U1.31 (D15/A-1), U3.2 (D0)
/LT: U2.11 (Load), U3.11 (Load), U6.3, U6.4, U6.5
/~CS: J9.1, U1.12 (~CE)
/~LDI: J11.1, R6.1, U5.19 (CE)
/~RD: U1.14 (~OE), U6.6
GND: C1.2, C2.2, C3.2, C4.2, C5.2, C6.2, C7.2, J1.1, J2.1, J3.1, J4.2, J5.1, J6.1, J7.1, J8.1, J12.1, J13.1, J14.1, Q1.1 (G), RN1.1 (common), RN2.1 (common), RN3.1 (common), U1.13 (GND), U1.32 (GND), U1.34 (A16), U2.1 (OE), U2.10 (GND), U3.1 (OE), U3.10 (GND), U4.10 (GND), U4.19 (CE), U5.10 (GND), U6.7 (GND), U6.9, U6.10, U6.12, U6.13, U7.10 (GND), U7.19 (CE)
unnamed: BAR1.11 (K), RN2.2 (R1)
unnamed: BAR1.12 (K), RN2.3 (R2)
unnamed: BAR1.13 (K), RN2.4 (R3)
unnamed: BAR1.14 (K), RN2.5 (R4)
unnamed: BAR1.15 (K), RN2.6 (R5)
unnamed: BAR1.16 (K), RN2.7 (R6)
unnamed: BAR1.17 (K), RN2.8 (R7)
unnamed: BAR1.18 (K), RN2.9 (R8)
unnamed: BAR2.11 (K), RN3.2 (R1)
unnamed: BAR2.12 (K), RN3.3 (R2)
unnamed: BAR2.13 (K), RN3.4 (R3)
unnamed: BAR2.14 (K), RN3.5 (R4)
unnamed: BAR2.15 (K), RN3.6 (R5)
unnamed: BAR2.16 (K), RN3.7 (R6)
unnamed: BAR2.17 (K), RN3.8 (R7)
unnamed: BAR2.18 (K), RN3.9 (R8)
unnamed: J4.1, Q1.3 (D)
unnamed: R1.1, U1.43 (~WE), U1.44 (~RESET)
unnamed: R2.1, U1.33 (~BYTE)
unnamed: R3.1, U7.1 (A->B)
unnamed: R4.1, U4.1 (A->B)
unnamed: R5.1, U5.1 (A->B)
unnamed: U2.12 (Q7), U7.9 (A7)
unnamed: U2.13 (Q6), U7.8 (A6)
unnamed: U2.14 (Q5), U7.7 (A5)
unnamed: U2.15 (Q4), U7.6 (A4)
unnamed: U2.16 (Q3), U7.5 (A3)
unnamed: U2.17 (Q2), U7.4 (A2)
unnamed: U2.18 (Q1), U7.3 (A1)
unnamed: U2.19 (Q0), U7.2 (A0)
unnamed: U3.12 (Q7), U4.9 (A7)
unnamed: U3.13 (Q6), U4.8 (A6)
unnamed: U3.14 (Q5), U4.7 (A5)
unnamed: U3.15 (Q4), U4.6 (A4)
unnamed: U3.16 (Q3), U4.5 (A3)
unnamed: U3.17 (Q2), U4.4 (A2)
unnamed: U3.18 (Q1), U4.3 (A1)
unnamed: U3.19 (Q0), U4.2 (A0)
VCC: C1.1, C2.1, C3.1, C4.1, C5.1, C6.1, C7.1, Q1.2 (S), R1.2, R2.2, R3.2, R4.2, R5.2, R6.2, U1.23 (VCC), U2.20 (VCC), U3.20 (VCC), U4.20 (VCC), U5.20 (VCC), U6.14 (VCC), U7.20 (VCC)

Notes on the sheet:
COMMAND
CONST/ADDR
ToDo: Check it! Probably C1 have to be inverted!



Board: 2 copper layers, 149.9 x 99.1 mm, 46 parts (7 on the bottom side), 101 nets.

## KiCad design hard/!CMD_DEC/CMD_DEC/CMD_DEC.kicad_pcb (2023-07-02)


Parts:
C1, C3, C4, C5, C6: 0.1uF; C_0805_2012Metric_Pad1.18x1.45mm_HandSolder
D1: LED; LED_D5.0mm
H1, H2, H3: MountingHole; MountingHole_3.2mm_M3
J1, J16: Conn_01x04_Male; PinHeader_1x04_P2.54mm_Vertical
J2, J7, J8, J9, J10, J11, J12, J13, J17, J18, J19: Conn_01x01_Male; PinHeader_1x01_P2.54mm_Vertical
J3: Conn_01x05_Male; PinHeader_1x05_P2.54mm_Vertical
J4, J5: Conn_01x08_Male; PinHeader_1x08_P2.54mm_Vertical
J6: Conn_01x02_Male; PinHeader_1x02_P2.54mm_Vertical
J14: Screw_Terminal_01x02; TerminalBlock_Phoenix_MKDS-1,5-2_1x02_P5.00mm_Horizontal
J15: Conn_01x03_Male; PinHeader_1x03_P2.54mm_Vertical
R1, R2: 10k; R_0805_2012Metric_Pad1.20x1.40mm_HandSolder
R5: 1k; R_0805_2012Metric_Pad1.20x1.40mm_HandSolder
U1: 74LS08; DIP-14_W7.62mm_Socket
U2, U4: 74LS138; DIP-16_W7.62mm_Socket
U3: 74LS139; DIP-16_W7.62mm_Socket
U5: 74LS85; DIP-16_W7.62mm_Socket
U6: 74HC00; DIP-14_W7.62mm_Socket

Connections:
/C1: J2.1, U2.5 (E2), U4.5 (E2)
/C2: J13.1, U1.2, U6.10
/CF_EN: J12.1, U6.3
/CMP_EN: J11.1, U6.6
/COP[0]: J1.1, U2.1 (A0), U4.1 (A0), U5.10 (A0)
/COP[1]: J1.2, U2.2 (A1), U4.2 (A1), U5.12 (A1)
/COP[2]: J1.3, U2.3 (A2), U4.3 (A2), U5.13 (A2)
/COP[3]: J1.4, U2.4 (E1), U4.6 (E3), U5.15 (A3)
/LATCH_REG: J8.1, U1.3
/SRC[0]: J6.1, U3.14 (A0)
/SRC[1]: J6.2, U3.13 (A1)
/WILL_WR2REG: J18.1, R5.1, U1.1, U5.7 (Oa<b)
/~ADD: J4.1, U1.4, U2.15 (O0)
/~ADDC: J4.2, U1.5, U2.14 (O1)
/~ADDx: J9.1, U1.6, U6.1
/~AND: J4.3, U2.13 (O2)
/~BRANCH: J5.8, U4.7 (O7)
/~CMP: J5.7, U4.9 (O6), U6.4, U6.5
/~CTRL: J5.6, U4.10 (O5)
/~IN: J5.3, U4.13 (O2)
/~INV: J3.1, U3.12 (O0)
/~LD: J5.2, J17.1, U1.9, U4.14 (O1)
/~LDI: J5.1, U4.15 (O0)
/~LSR: J3.3, U1.13, U3.10 (O2)
/~LSRC: J3.4, U1.12, U3.9 (O3)
/~LSRx: J3.5, U1.11, U6.2
/~MOV: J4.7, U2.9 (O6)
/~MUL: J4.8, J19.1, U2.7 (O7)
/~OR: J4.4, U2.12 (O3)
/~OUT: J5.4, U4.12 (O3)
/~RAM_CS: J7.1, U1.8
/~RAM_WR: J10.1, U6.8
/~ST: J5.5, U1.10, U4.11 (O4), U6.12, U6.13
/~SWAP: J3.2, U3.11 (O1)
/~UNO: J4.6, U2.10 (O5), U3.15 (E)
/~XOR: J4.5, U2.11 (O4)
GND: C1.2, C3.2, C4.2, C5.2, C6.2, D1.1 (K), J14.2, U1.7 (GND), U2.8 (GND), U3.8 (GND), U4.4 (E1), U4.8 (GND), U5.2 (Ia<b), U5.4 (Ia>b), U5.8 (GND), U5.14 (B2), U6.7 (GND)
unnamed: D1.2 (A), R5.2
unnamed: J15.1, U3.3 (A1)
unnamed: J15.2, U3.2 (A0)
unnamed: J15.3, U3.1 (E)
unnamed: J16.1, U3.4 (O0)
unnamed: J16.2, U3.5 (O1)
unnamed: J16.3, U3.6 (O2)
unnamed: J16.4, U3.7 (O3)
unnamed: R1.1, U2.6 (E3)
unnamed: R2.1, U5.1 (B3), U5.3 (Ia=b), U5.9 (B0), U5.11 (B1)
unnamed: U6.9, U6.11
VCC: C1.1, C3.1, C4.1, C5.1, C6.1, J14.1, R1.2, R2.2, U1.14 (VCC), U2.16 (VCC), U3.16 (VCC), U4.16 (VCC), U5.16 (VCC), U6.14 (VCC)

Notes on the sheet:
< 1011
Signal C1 temporarily disables the outputs to avoid short circuits on commands outputs.
1011



Board: 2 copper layers, 78.7 x 50.8 mm, 37 parts (3 on the bottom side), 49 nets.

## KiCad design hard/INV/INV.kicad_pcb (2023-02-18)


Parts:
C1, C2, C3: 0.1uF; C_0805_2012Metric_Pad1.18x1.45mm_HandSolder
D1: LED; LED_0805_2012Metric_Pad1.15x1.40mm_HandSolder
J1, J2: Conn_01x08_Male; PinHeader_1x08_P2.54mm_Horizontal
J3: Conn_01x04_Male; PinHeader_1x04_P2.54mm_Horizontal
R1: 1k; R_0805_2012Metric_Pad1.20x1.40mm_HandSolder
U1, U3: 74HC00; SO-14_3.9x8.65mm_P1.27mm
U2: 74LS573; SOIC-20W_7.5x12.8mm_P1.27mm

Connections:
/Latch: J3.4, U2.11 (Load)
/O0: J2.8, U2.12 (Q7)
/O1: J2.7, U2.13 (Q6)
/O2: J2.6, U2.14 (Q5)
/O3: J2.5, U2.15 (Q4)
/O4: J2.4, U2.16 (Q3)
/O5: J2.3, U2.17 (Q2)
/O6: J2.2, U2.18 (Q1)
/O7: J2.1, U2.19 (Q0)
/~OE: J3.1, R1.2, U2.1 (OE)
GND: C1.2, C2.2, C3.2, J3.2, U1.7 (GND), U2.10 (GND), U3.7 (GND)
unnamed: D1.1 (K), R1.1
unnamed: J1.1, U3.9, U3.10
unnamed: J1.2, U3.12, U3.13
unnamed: J1.3, U3.4, U3.5
unnamed: J1.4, U3.1, U3.2
unnamed: J1.5, U1.9, U1.10
unnamed: J1.6, U1.12, U1.13
unnamed: J1.7, U1.4, U1.5
unnamed: J1.8, U1.1, U1.2
unnamed: U1.3, U2.9 (D7)
unnamed: U1.6, U2.8 (D6)
unnamed: U1.8, U2.6 (D4)
unnamed: U1.11, U2.7 (D5)
unnamed: U2.2 (D0), U3.8
unnamed: U2.3 (D1), U3.11
unnamed: U2.4 (D2), U3.6
unnamed: U2.5 (D3), U3.3
VCC: C1.1, C2.1, C3.1, D1.2 (A), J3.3, U1.14 (VCC), U2.20 (VCC), U3.14 (VCC)

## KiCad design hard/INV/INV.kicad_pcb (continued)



Board: 2 copper layers, 61.0 x 26.7 mm, 11 parts (3 on the bottom side), 29 nets.

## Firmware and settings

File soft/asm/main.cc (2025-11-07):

#include <iostream>
#include <windows.h>

#include "assm.h"

using namespace std;

void help() {
  const char* help_lines[] = {
      "74HCPU assembler v 0.4\n",
      "Support next operations:\n",
      "arithmetic: ADD, ADDC, AND, OR, XOR, MUL, UNO (SWAP, INV, LSR, LSRC), MOV\n",
      "memory: LPM, LD, ST\n",
      "port: IN, OUT\n",
      "compare: CMP, CMPC\n",
      "jmp: CALL, JMP, RET, JZ, JL, JNE, JE, JG, JC, JNZ, JNC, JHC, JNHC, STOP, AFCALL, NOP\n",
      "Registers: R0, R1, R2, R3, R4, R5, R6, R7\n",
      "Register pointers: X(XL+XH), Y(YL+YH), Z(ZL+ZH), SP(SPL+SPH)\n",
      "Auto-increment pointers: XI, YI, ZI, SPI\n",
      "Auto-decrement pointers: XD, YD, ZD, SPD\n",
      "PORTS: PORT0-31, PIN0-31\n",
      "Macro: LO()/HI() for pointers, for example:\nmov YL, LO(StringName)\n",
      "Directives:\n.org 1000h\n.str S \"Some str\"\n.def FROM TO\n.def FROM(param) TO param, bla-bla\n",
      ".def push(r) ST SPD, r ; example for .def with param\n",
      "\nRun:\n",
      "74hc-asm.exe src.asm [-pre]\n",
      " -pre will print preprocessed src.asm\n",
      "74hc-asm.exe src.asm out.hex\n",
      " will create result binary out.hex\n",
      nullptr
  };

  int i = 0;
  while (help_lines[i]) {
    cout << help_lines[i];
    i++;
  }
}

int main(int argc, char* argv[]) {
  SetConsoleOutputCP(CP_UTF8);

  if (argc < 2) {
    help();
    return 0;
  }

  if (argc >= 2 && argv[1]) {
    string cmd(argv[1]);
    if (cmd == "help") {
      help();
      return 0;
    }

    bool show_pre {false};
    if (argc > 2 && string(argv[2]) == "-pre")
      show_pre = true;

    // okay, probably cmd is file name ;)
    try {
      Assembler assm;
      bool res = assm.process(cmd, show_pre);
      if (argc > 2 && argv[2] && !show_pre && !res)
        assm.write_binary(argv[2]);
      return res;
    } catch (const char* e) {
      cout << "Error: " << e << endl;
    } catch (std::exception e) {
      cout << "Error: " << e.what() << endl;
    }
  }

  cout << "argc: " << argc << endl;
  return 0;
}

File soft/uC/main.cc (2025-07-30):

#include <iostream>
#include <fstream>
#include <memory>
#include <stdexcept>

#include "lexer.h"
#include "parser.h"

/*

Данный компилятор имеет два места, которые владеют объектами:

 * словарь внутри лексера, в котором накапливаются идентификаторы,
     и который удаляется в его деструкторе
 * собственно дерево разбора, вершина которого хранится в парсере, а остальные узлы крепятся к вершине
     и которые удаляются в его деструкторе

Все остальные места просто хранят указатели на эти объекты, но не удаляют их.

*/

using namespace std;

int main(int argc, char* argv[]) {
  if (argc != 2) {
    cout << "To use type: 74hc-uC.exe <source file name>" << endl;
    return 1;
  }

  string name(argv[1]);
  cout << "Processing: " << name << endl;

  ifstream f;
  f.open(name, ios::in);
  if (!f) {
    cout << "Error. Can't open file: " << name << endl;
    return 1;
  }

  try {
    Lexer lex(f);
    Parser parse(&lex);
    parse.program();
  } catch (const std::runtime_error& e) {
      // Catch the runtime_error and print its message
      cerr << "Caught runtime error: " << e.what() << endl;
  }

  cout << endl;

  return 0;
}

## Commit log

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2020-09-03 New template + 74HC573
    [AND.kicad_pcb, AND.sch]
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2022-02-04 Fix board list
2022-02-12 Update command pcb template
    [template.kicad_pcb, template.sch]
2022-02-12 2x size template for command pcb
    [template-b.kicad_pcb, template-b.sch]
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2022-02-18 Prototype boards for cmd
    [template-b.kicad_pcb, template.kicad_pcb]
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2022-02-21 Update cmd template pcb
    [template-b.kicad_pcb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]
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2022-02-21 Add 50x70 prototype board (T-shape)
    [Proto50x70-T.kicad_pcb, Proto50x70-T.sch]
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2022-03-07 ALU: A -> T
    [ALU.kicad_pcb, ALU.sch]
2022-03-07 ALU: B -> A
    [ALU.kicad_pcb, ALU.sch]
2022-03-07 ALU: T -> B
    [ALU.kicad_pcb, ALU.sch]
2022-03-07 ALU: A <-> B in CMD symbol
    [ALU.kicad_pcb]
2022-03-07 ALU: add RAM sockets
    [ALU.kicad_pcb, ALU.sch]
2022-03-07 Add one more out socket
    [ALU.kicad_pcb, ALU.sch]
2022-05-01 Playing with Regs pcb
    [Regs.kicad_pcb, Regs.sch]
2022-05-02 Regs pcb is ready
    [Regs.kicad_pcb, Regs.sch]
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2022-05-19 Mark LEDs like HLx
    [Regs.kicad_pcb, Regs.sch]
2022-05-19 Prepare to add Bank1
    [Regs.kicad_pcb, Regs.sch]
2022-05-20 MUX 8:1 is ready
    [MUX-B_Cu.gbr, MUX-B_Mask.gbr, MUX-B_SilkS.gbr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]
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2022-05-24 Regs v2 pcb in work
    [Regs-v2.kicad_pcb, Regs-v2.sch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]
2022-05-25 Regs v2 in work
    [Regs-v2.kicad_pcb, Regs-v2.sch]
2022-05-27 Make inputs active low
    [Reg.kicad_pcb, Reg.sch]
2022-05-28 MUX 8:1 in work
    [MUX.kicad_pcb, MUX.sch]
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2022-05-30 Add Enable pin. Make corners.
    [MUX.kicad_pcb, MUX.sch]
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2022-05-30 Add date & gerber
    [MUX-B_Cu.gbr, MUX-B_Mask.gbr, MUX-B_SilkS.gbr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]
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2022-06-01 ALU rework
    [ALU.kicad_pcb, ALU.sch]
2022-06-01 Working on Flags reg
    [ALU.sch]
2022-06-02 Add date & photomask
    [Regs-v2.kicad_pcb]
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2022-06-04 Fix corners
    [Regs-v2.kicad_pcb]
2022-06-04 Flags registry logic in work
    [ALU.sch]
2022-06-04 Reorder some logical items
    [ALU.kicad_pcb, ALU.sch]
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2022-06-08 Remove interrupt flag. Remove some logical items.
    [ALU.kicad_pcb, ALU.sch]
2022-06-09 Remove tracks, adjust sockets
    [ALU.kicad_pcb, ALU.sch]
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2022-06-12 Fix pinheader pos
    [Regs-v2.kicad_pcb]
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2022-06-20 Try to extract Flags register into separate pcb
    [Flags.dsn, Flags.kicad_pcb, Flags.sch]
2022-06-21 Extract Flags to separate pcb
    [ALU.sch]
2022-06-22 Place ICs on Flags pcb
    [Flags.dsn, Flags.kicad_pcb, Flags.sch]
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2022-06-28 Convert AND cmd to SMD
    [AND.dsn, AND.kicad_pcb, AND.sch]
2022-07-03 Polishing AND SMD cmd
    [AND.kicad_pcb, AND.sch]
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2022-07-09 Polishing ALU All components was placed
    [ALU.kicad_pcb, ALU.sch]
2022-07-09 ALU. Add some pwr tracks
    [ALU.dsn, ALU.kicad_pcb, ALU.sch]
2022-07-11 Some changes in ALU
    [ALU.dsn, ALU.kicad_pcb, ALU.sch]
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2022-07-11 Lost date & name
    [AND.kicad_pcb]
2022-07-27 MUX 4:1, circuit diagram & components placement
    [MUX4x1.dsn, MUX4x1.kicad_pcb, MUX4x1.sch]
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2022-07-28 We need more sockets!!
    [MUX4x1.kicad_pcb, MUX4x1.sch]
2022-07-31 MUX4:1 - we need more rivets!!
    [MUX4x1.kicad_pcb]
2022-10-21 AND SMD PCB is ready
    [AND-B_Cu.gbr, AND-B_Mask.gbr, AND-B_SilkS.gbr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]
2022-10-21 MUX 4:1 PCB is ready
    [MUX4x1-B_Cu.gbr, MUX4x1-B_Mask.gbr, MUX4x1-B_SilkS.gbr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]
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2022-10-22 Fix PCB margin
    [ADD.kicad_pcb, AND.kicad_pcb]
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2022-10-30 Polishing AND cmd Add date & label
    [AND.kicad_pcb, AND.sch]
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2022-11-04 Ports PCB is ready
    [Ports.kicad_pcb, Ports.sch]
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2022-11-05 CMP cmd is ready
    [CMP.dsn, CMP.kicad_pcb, CMP.sch]
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2022-11-05 MUX4:1 v3 Rotated some sockets
    [MUX4x1.dsn, MUX4x1.kicad_pcb, MUX4x1.sch]
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2022-11-12 Polishing MUL. Add gerber.
    [MUL1-B_Cu.gbr, MUL1-B_Mask.gbr, MUL1-B_SilkS.gbr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]
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2022-11-23 MUX8x1, 4 layer, first try
    [MUX8x1-v3-B_Cu.gbr, MUX8x1-v3-B_Mask.gbr, MUX8x1-v3-B_SilkS.gbr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]
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2022-11-24 Epic fail. Fix power supply on ADD.
    [ADD.kicad_pcb, ADD.sch]
2022-11-25 Swap A & B busses.
    [AND.kicad_pcb, AND.sch]
2022-11-25 Add NAND to ADD cmd
    [ADD.kicad_pcb, ADD.sch]
2022-11-25 Fix font size
    [ADD.kicad_pcb]
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2022-11-27 Print settings? Photo mask
    [CMP.kicad_pcb]
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2022-12-01 Invertor for SUB cmd implementation
    [INV.kicad_pcb, INV.sch]
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2022-12-02 Print settings for 273
    [273-B_Cu.gbr, 273-B_Mask.gbr, 273-B_SilkS.gbr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]
2022-12-02 Print settings for MUX4:1
    [MUX4x1-B_Cu.gbr, MUX4x1-B_Mask.gbr, MUX4x1-B_SilkS.gbr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]
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2022-12-02 Polishing MUX8:1 v3 (150x70)
    [MUX8x1-v3-B_Cu.gbr, MUX8x1-v3-B_Mask.gbr, MUX8x1-v3-B_SilkS.gbr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]
2022-12-10 Fix text & date
    [LSL.kicad_pcb, LSR.kicad_pcb]
2022-12-10 Fix silk
    [AND.kicad_pcb]
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2022-12-14 Fix fonts
    [ADD.kicad_pcb, AND.kicad_pcb, INV.kicad_pcb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]
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2022-12-20 SWAP cmd
    [SWAP.kicad_pcb, SWAP.sch]
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2022-12-20 Add photo mask for SWAP
    [SWAP.kicad_pcb]
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2022-12-24 Polishing SWAP cmd
    [SWAP.kicad_pcb, SWAP.sch]
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2022-12-26 Swap OE & UseCF pins
    [LSL.kicad_pcb, LSL.sch, LSR.kicad_pcb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]
2022-12-26 Swap UseCF & OE
    [ADD.kicad_pcb, ADD.sch]
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2023-01-21 Wrong silk
    [ADD.kicad_pcb]
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2023-02-18 Fix some silk & power tracks
    [MUX4x1-B_Cu.gbr, MUX4x1-B_Mask.gbr, MUX4x1-B_SilkS.gbr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]
2023-02-18 Fix some silk
    [MUX8x1-v5-B_Cu.gbr, MUX8x1-v5-B_Mask.gbr, MUX8x1-v5-B_SilkS.gbr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]
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2023-02-18 Some fixes for panelization
    [INV.kicad_pcb, LSL.kicad_pcb, LSR.kicad_pcb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]
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2023-02-19 Remove some flags, fix board size
    [Flags.dsn, Flags.kicad_pcb, Flags.sch]
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2023-02-19 SWAP CF & ZF
    [JMPS.kicad_pcb, JMPS.sch]
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2023-02-24 Fix origin?
    [CMP.kicad_pcb]
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2023-02-24 Fix pins & text
    [Flags.kicad_pcb]
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2023-02-26 JUMPS. Fix Pads.
    [JMPS.kicad_pcb]
2023-02-28 Fix mistype on silk
    [Flags.kicad_pcb]
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2023-04-26 Fix silk on CMP
    [CMP.kicad_pcb]
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2023-05-21 AND cmd. Swap SRC & DST busses
    [AND.kicad_pcb, AND.sch]
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2023-06-27 fix CMP pcb
    [CMP.kicad_pcb, CMP.sch]
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2023-07-12 Reverse bits order
    [Reg.dsn, Reg.kicad_pcb, Reg.sch]
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2023-07-12 Fix print settings. Add gerbers
    [CMP-B_Cu.gbr, CMP-B_Mask.gbr, CMP-B_SilkS.gbr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]
2023-07-12 Fix socket on ROM: tssop48 -> so44
    [ROM.kicad_pcb, ROM.sch]
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2023-07-15 Fix print settings. Add photomask
    [Toggle.kicad_pcb]
2023-07-15 Fix mirror flag. Update photomask
    [Toggle.kicad_pcb]
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2023-07-17 Ports. Fix mounting holes position.
    [Ports.kicad_pcb]
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2023-07-22 Ports. Fix pin name
    [Ports.kicad_pcb]
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2023-07-25 ALU. Add reverse polarity protection.
    [ALU.kicad_pcb, ALU.sch]
2023-07-25 RAM. Add reverse polarity protection.
    [RAM.kicad_pcb, RAM.sch]
2023-07-28 MUX8:1 - Now it have 2 zero line
    [MUX8x1-v5.kicad_pcb, MUX8x1-v5.sch]
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2024-01-13 MUX8:1 with rotated/reverted OUT socket
    [MUX8x1-v5.kicad_pcb, MUX8x1-v5.sch]
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2024-01-14 LED8: fix size between LED & R
    [LED8.kicad_pcb]
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2024-01-16 Regs: now SP initial address can be 8000h
    [Regs-v3.kicad_pcb, Regs-v3.sch]
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2024-01-21 Polishing Regs v3 Move pinheaders to other side.
    [Regs-v3.kicad_pcb]
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2024-01-21 Regs v3: add 2 additional reset output
    [Regs-v3.kicad_pcb, Regs-v3.sch]
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2024-02-03 Regs v4: in work (2 bank by 8 register, first bank for arithmetic, second bank for pointers)
    [Regs-v4.kicad_pcb, Regs-v4.sch]
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2024-03-12 gerbers for MUX8x1 reverted
    [MUX8x1-v5-B_Cu.gbr, MUX8x1-v5-B_Mask.gbr, MUX8x1-v5-B_Paste.gbr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]
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2024-03-20 Register with LEDs & reset is ready
    [Reg.kicad_pcb, Reg.sch]
2024-03-20 Wrong folder. Just rename.
    [Reg.kicad_pcb, Reg.sch]
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2024-03-21 Add gerbers, fix PTH for Regs v4
    [Regs-v4-B_Cu.gbr, Regs-v4-B_Mask.gbr, Regs-v4-B_SilkS.gbr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]
2024-03-24 uC in work: fix headers
    [main.cc]
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2024-06-13 MUX4:1, 1bit - set minimum size == 12.7mm
    [MUX1-B_Cu.gbr, MUX1-B_Mask.gbr, MUX1-B_Paste.gbr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]
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2024-06-16 Address counter in work. Set power pins in center of the MUX PCB.
    [MUX16bit.kicad_pcb]
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2024-06-16 Fix MUX1 (4:1, 1 bit) sizes. Set 10mm between power and other pins.
    [MUX1.kicad_pcb]
2024-06-16 Fix MUX1 gerbers.
    [MUX1-B_Cu.gbr, MUX1-B_Mask.gbr, MUX1-B_Paste.gbr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]
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2024-07-20 Set "standard" size for RAM (99.06 x 99.06)
    [RAM.kicad_pcb]
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2024-07-21 Old MUX8:1 - fix silk
    [MUX8x1-v5.kicad_pcb]
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2024-07-22 RAM - move data socket to left side
    [RAM-B_Cu.gbr, RAM-B_Mask.gbr, RAM-B_SilkS.gbr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]
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2024-07-24 Invertor doesn't have output buffer so I removed output pinheaders
    [ALU-B_Cu.gbr, ALU-B_Mask.gbr, ALU-B_SilkS.gbr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]
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2024-08-13 ROM in work Try to rotate ROM socket
    [ROM.kicad_pcb, ROM.sch]
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2024-08-14 Bug fix ALU Update gerber
    [ALU-B_Cu.gbr, ALU-B_Mask.gbr, ALU-B_SilkS.gbr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]
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2024-08-16 Ports v1.4 Polishing, move power connector to left
    [Ports-B_Cu.gbr, Ports-B_Mask.gbr, Ports-B_SilkS.gbr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]
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2025-11-04 Fix debug print
2025-11-07 Replace static methods to Singleton & our class
    [main.cc]
2025-11-07 Fix command line args processing
    [main.cc]
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
